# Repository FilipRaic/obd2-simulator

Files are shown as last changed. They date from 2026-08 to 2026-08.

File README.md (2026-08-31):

# OBD-II Simulator

Open-source OBD-II simulator board that answers a diagnostic tool over CAN
exactly as a vehicle ECU does. The repository has three parts:

- the **protocol core** (`include/`, `src/`, `tests/`) - portable,
  host-testable protocol and simulation layers with no external
  dependencies, described below,
- the **firmware** (`firmware/`) - PlatformIO project for the device
  itself (FreeRTOS tasks, MCP2515 SPI driver, TFT_eSPI user interface,
  16 MB SPI NOR flash storage with USB-C MSC / USB-A stick transfer), which
  compiles the core unchanged and plugs into it through the small set of
  `extern` platform hooks listed below. See `firmware/README.md`,
- the **board** (`hardware/`) - the KiCad project, gerbers, bill of
  materials and the scripts that generate the board, at revision **v0.7**
  (130 x 115 mm, two-layer FR4, ESP32-S3-WROOM-1). See `hardware/README.md`.

Block diagram of the OBD-II simulator, five functional blocks

The simulator answers a diagnostic tool over CAN and, like a real vehicle, powers
it from pin 16 of the J1962 connector. The protocol core described below is what
runs inside the "Microcontroller" block, and everything around it is documented
in [`hardware/README.md`](hardware/README.md), which walks through the same
schematics one design decision at a time.

Everything in the repository is in English. The project also keeps a set of
Croatian working documents, which live outside it.

The **v0.7 board has been fabricated and assembled** in one unit. A commercial
ELM327 adapter connects to it, reads all 21 parameters and the fault codes, and
draws its own 12 V from pin 16 while doing so.

## The website

The project has a landing page at **<https://filipraic.github.io/obd2-simulator/>**,
which is the short version of everything below: what the device does, what it is
built from and where to get the files. Two things on it are worth opening even if
the page itself is skipped, because neither can be shown in a README:

| Page | What it is |
|---|---|
| [The user interface demo](https://filipraic.github.io/obd2-simulator/UI-demo/) | the screens `firmware/src/ui/screens/` draws on the display, redrawn in a browser and walked with the same encoder and joystick controls the device has, so the interface can be tried before anything is built |
| [The interactive board view](https://filipraic.github.io/obd2-simulator/OBD2-board-v0.7/) | the v0.7 board drawn in the browser, with the tracks, the ground pour, the vias, the pads and the components as five layers that switch on and off, and a tooltip on every part. Generated from `obd2-simulator.kicad_pcb` by `hardware/kicad/scripts/generate_pcb_html.py` |

## Where to read what

The wiki is written for someone using or rebuilding the device. The files in
this repository are the record of how it was built and why. The wiki is in
English, which is the language of the project. A Croatian translation of the
same pages exists but is not published yet, and if it goes up it will take an
`-HR` suffix, leaving the page names below unchanged.

| Question | Wiki page | In this repository |
|---|---|---|
| What is this and what can it do | [Home](../../wiki/Home) | this file |
| How do I build one | [Building the device](../../wiki/Building-the-device) | [`hardware/README.md`](hardware/README.md), and [`hardware/gerber/README.md`](hardware/gerber/README.md) before ordering |
| How do I compile and flash it | [Firmware](../../wiki/Firmware) | [`firmware/README.md`](firmware/README.md), and [`firmware/tools/README.md`](firmware/tools/README.md) when the ordinary upload path is unavailable |
| How do I drive it | [Usage](../../wiki/Usage) | [`scenarios/README.md`](scenarios/README.md) for the JSON format |
| How do I contribute | [Contributing](../../wiki/Contributing) | the conventions below |
| How is the board generated | - | [`hardware/kicad/scripts/README.md`](hardware/kicad/scripts/README.md) |

Two internal documents govern changes to this project, and neither is published
here: `docs/MAPA-POVEZANIH-DATOTEKA.md` is an "if you change X, check Y" table,
because the same fact is written down in up to six places, and
`docs/combined/DNEVNIK-IZMJENA.md` is the chronological record of every decision.
Both are in Croatian and are working notes rather than product documentation, so
`docs/` is deliberately left out of the repository.

## Modules

| File | Purpose |
|---|---|
| `include/obd2_pids.h` | Mode/PID constants per SAE J1979 / ISO 15031-5 |
| `include/sensor_table.h` | 21 simulated parameters with ranges and noise |
| `src/pid_encoder.cpp` | Value → raw bytes codec + supported-PID bitmasks |
| `include/dtc_bank.h` | DTC bank (pending/confirmed, MIL, freeze frame) |
| `src/iso_tp.cpp` | ISO 15765-2 transmit path (SF, FF/FC/CF) |
| `src/can_handler.cpp` | Request dispatcher, modes 0x01-0x09 |
| `src/simulator_core.cpp` | Simulation profiles (Manual / Idle / Drive) |
| `tests/test_simulator.cpp` | Host-side unit tests |

Implemented services: 0x01 (current data, 21 PIDs), 0x02 (freeze frame),
0x03/0x07 (stored/pending DTCs), 0x04 (clear DTCs), 0x09 (VIN).
Unsupported services receive the negative response `7F <mode> 11`.
Requests are accepted on 0x7DF (functional) and 0x7E0 (physical), while
responses are sent on 0x7E8. Frames are padded to 8 bytes with 0x55
per ISO 15765-4.

## Platform hooks (implement on target, stubbed in tests)

```cpp
uint32_t millis();                                // ms since boot
void     can_send_frame(const CanFrame& frame);   // MCP2515 transmit
bool     iso_tp_wait_flow_control(FlowControl&);  // wait for FC frame
void     iso_tp_delay_us(uint32_t us);            // STmin pacing
```

## Building and running the tests

```sh
cmake -B build
cmake --build build
ctest --test-dir build --output-on-failure
```

The same tests also run through PlatformIO (`pio test -e native` inside
`firmware/`). Firmware build: `pio run -e custom-board` (the dedicated
ESP32-S3 board, also used on the breadboard adapter during development).

## Regenerating the board

The board is generated rather than drawn: there is no `.kicad_sch`, and the
`.kicad_pcb` is an output. Two entry points, and picking the wrong one costs
work:

```powershell
# a part, a net or the placement changed - rebuilds and re-routes from nothing
powershell -ExecutionPolicy Bypass -File hardware\kicad\scripts\route_board.ps1

# the board file is already right, only the derived files are stale
powershell -ExecutionPolicy Bypass -File hardware\kicad\scripts\regen_outputs.ps1
```

`route_board.ps1` ends by recomputing all 103 reference designator positions and
so **discards the hand-tuned silkscreen**. If no copper moved, run only
`regen_outputs.ps1`. Every step of the chain, what it writes and where, is in
[`hardware/kicad/scripts/README.md`](hardware/kicad/scripts/README.md).

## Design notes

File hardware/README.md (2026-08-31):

# OBD-II simulator board, revision v0.7

The final hardware of the project: a dedicated two-layer board **130 x 115 mm**
with an ESP32-S3-WROOM-1 module, the CAN chain MCP2515 -> SN65HVD230 ->
PESD1CAN -> J1962F, and power over USB-C Power Delivery.

Block diagram of the OBD-II simulator, five functional blocks

The five blocks in that diagram are the ones the rest of this document keeps
naming: **power** (USB-C PD to 12 V and 3,3 V), the **CAN and OBD interface**
(MCP2515 to SN65HVD230 to the J1962F socket), the **microcontroller**, **memory
and USB**, and the **user interface**. The dashed arrow is the diagnostic tool,
which the simulator both answers and powers, over pin 16 of the connector.

Every figure in this file is drawn by `kicad/scripts/generate_figures.py`. It
draws them **by hand rather than deriving them from the board**, so a figure does
not follow a board change on its own, and after a change to the schematic it has
to be redrawn there. The full set is listed in [Figures](#figures) below.

The board **has been fabricated and assembled** in one unit, and the core of the
device was verified on it with a commercial ELM327 adapter. Numbers about the
board itself are still measured from the project file
`kicad/obd2-simulator.kicad_pcb` or taken from tool output, never copied from an
earlier version of this text.

Wiki page for anyone building one: **Building the device**, on the repository
wiki. It has the bill of materials, the pinout and the first-power-up procedure. This
file is the design record behind those instructions, decision by decision.

**How the board is generated is a subject of its own**, and it has its own index
in [`kicad/scripts/README.md`](kicad/scripts/README.md): which of the two entry
points to run, what each step of the routing chain is for and which derived file
lands where.

## Board state (measured with the tools)

| Item | State |
|---|---|
| Outline | 130 x 115 mm, two-layer FR4 1,6 mm, 4 x M3 in the corners (spacing 120,00 x 105,00 mm) |
| Footprints | **107** (95 parts to solder + 8 test points + 4 mounting holes), of which **16 SMD** |
| Nets | **64 named**, ground included |
| Routing | **892 segments** (639 top layer, 253 bottom), **73 vias** (72 x 0,60 / 0,30 mm and one x 0,80 / 0,40 mm on V5_STICK), fully routed |
| DRC | **0 errors, 0 warnings, 0 unconnected** (`kicad-cli pcb drc --severity-all`) |
| Mask | black, silkscreen white, ENIG finish |
| Components | all on the top side, the bottom is copper, mask and legend only |

A note on that DRC: it is clean **partly because some rules are switched off**.
The project has `min_silk_clearance = 0` and
`solder_mask_to_copper_clearance = 0`, and `missing_courtyard` is set to
"ignore". The claim "0 warnings" therefore does not by itself mean the silkscreen
has been checked.

**Checked separately on 10.08.2026.** by running DRC over a copy of the project
with those rules restored (`min_silk_clearance` 0,15 mm,
`solder_mask_to_copper_clearance` 0,05 mm, hole spacing 0,50 mm). Outcome:

| Finding | Count | Verdict |
|---|---|---|
| Silkscreen over a pad | **0** | clean, the earlier suspicion is settled |
| Mask bridge between nets | **0** | the openings do not merge, but the bridges are 0,150 mm, see below |
| Silkscreen clipped by the board edge | 2 | J4, 0,140 mm, cosmetic |
| Hole spacing under 0,50 mm | 21 | see `gerber/README.md`, the geometry of connector J1 |
| Footprint type does not match its pads | 1 | U1, an attribute of a custom footprint, no effect on fabrication |

## Contents of this directory

| Contents | What it is |
|---|---|
| `kicad/obd2-simulator.kicad_pcb` | The KiCad board project: footprints, netlist, placement, routing, ground pour, keepout around the antenna |
| `kicad/scripts/` | the scripts that generate the board (KiCad Python API + Freerouting), together with `PRE-FABRICATION-CHECKLIST.md` |
| `kicad/scripts/docx/` | `.docx` tooling that needs no Word: `md2docx.py` builds the technical documentation from Markdown, the rest edit text, tables and the table of contents. Moved here 15.08.2026., has its own `README.md` |
| `kicad/footprints/obd2.pretty/` | custom footprints: CH224K, SEP-A-OBD-D2, SKRHABE010, RK12L12C0A0G |
| `kicad/3dmodels/` | custom VRML models for the render, generated by `scripts/gen_3dmodels.py` |
| `kicad/render-top.png`, `render-bottom.png` | 3D renders of both sides, **embedded in this README**, so a stale render is visible on GitHub |
| `gerber/` | Gerber layers, Excellon drill, gbrjob and the package for the fabricator |
| `schema1.svg` - `schema4.svg`, `blok.svg`, `canchain.svg` | schematics and the block diagram, in English, generated by `scripts/generate_figures.py`. **Not used in the written documentation**, see the note below the table |
| `kicad/scripts/fig/` | every figure the generator draws. The six above are copied up into this directory, and three more are used from here: `zones.svg` (functional zone layout), `nets.svg` (all net groups with their routing rule) and `ip2368.svg` (the external circuit of the CH224K, the file name is that of the part the design started with) |
| `bom/bom-pcb.csv` | parts list with suppliers, order codes and prices |
| `bom/bom-pcb.md` | quantities, values, tolerances and packages, with soldering notes |

The 1:1 print document (`pcb-ispis-1-1-v07.docx`) and the figure generator of
the written documentation (`alati/figgen/`) are **not in this repository**. They
exist only for that document and live beside it. Every other script of
the project, including the ones that write into that directory, has lived here
in `kicad/scripts/` since 15.08.2026.

The **dimensioned drawing** (`tehnicki-crtez-pcb-v07.svg` and `.png`) has lived
there too, in `Slike za rad/crtezi-ploce/`, since 15.08.2026., and
`regen_outputs.ps1` writes it straight into that directory. The English
schematics stay here, because this repository is in English.

The Croatian set of nine figures that used to be generated alongside them **is no
longer produced, and the files that were there have been deleted**. Comparing the
MD5 sums of every image in the written documentation showed nothing uses them, so
`--lang hr` was dropped from `regen_outputs.ps1`. The flag itself still works, if
a Croatian schematic is ever needed:

```powershell
& "$env:LOCALAPPDATA\Programs\KiCad\10.0\bin\python.exe" `
    kicad\scripts\generate_figures.py --lang hr
```

> ⚠️ **The schematics in this directory are not the ones in the written
> documentation.** That document embeds a **different** set of figures, from its
> own generator (`alati/figgen/`). The file names are the same
> (`schema1` to `schema4`, `blok`, `canchain`, `nets`, `zones`), but they are
> different drawings from a different generator. Verified on 15.08.2026. by
> comparing MD5 sums: every PNG from `figgen/out/` is embedded verbatim in that
> `.docx`, and from the board only the render `kicad/render-top.png` and the
> dimensioned drawing `tehnicki-crtez-pcb-v07.png`.
>
> The practical consequence: **changing a schematic here changes nothing in that
> document.** If a figure is needed there too, `figgen` is what gets edited. There
> is no longer a third group of identically named files, because the Croatian
> schematics in `crtezi-ploce/` were deleted on 15.08.2026.

## Figures

Nine drawings, and each one answers a different question. They are used
throughout this document where they explain a decision, and this is the index:

| Figure | Answers |
|---|---|
| [`blok.svg`](blok.svg) | What the device consists of and what talks to what. Start here |
| [`schema1.svg`](schema1.svg) | How 12 V and 3,3 V are made, and where the tool power on pin 16 comes from |
| [`schema2.svg`](schema2.svg) | The CAN interface end to end, MCP2515 to SN65HVD230 to termination to ESD to J1962F |
| [`schema3.svg`](schema3.svg) | The ESP32-S3 module, external flash U7 and the USB subsystem, with the SPI series termination and the test points |
| [`schema4.svg`](schema4.svg) | The user interface: display, encoder, the 5-way switch and the three buttons, with the filters |
| [`canchain.svg`](canchain.svg) | Only the CAN chain, in the order it is actually routed, with the measured distances |
| [`kicad/scripts/fig/zones.svg`](kicad/scripts/fig/zones.svg) | Which functional group sits where on the 130 x 115 mm outline |
| [`kicad/scripts/fig/nets.svg`](kicad/scripts/fig/nets.svg) | Every net group, its ESP32-S3 pins and the rule its routing had to obey |
| [`kicad/scripts/fig/ip2368.svg`](kicad/scripts/fig/ip2368.svg) | The external circuit of the CH224K PD sink, that is how one resistor picks the voltage |

To read the board itself rather than the intent, the two renders below show
what was actually built. They come out of `regen_outputs.ps1`, straight from
`obd2-simulator.kicad_pcb` with the board stackup colours, so they are the
board and not a drawing of it.

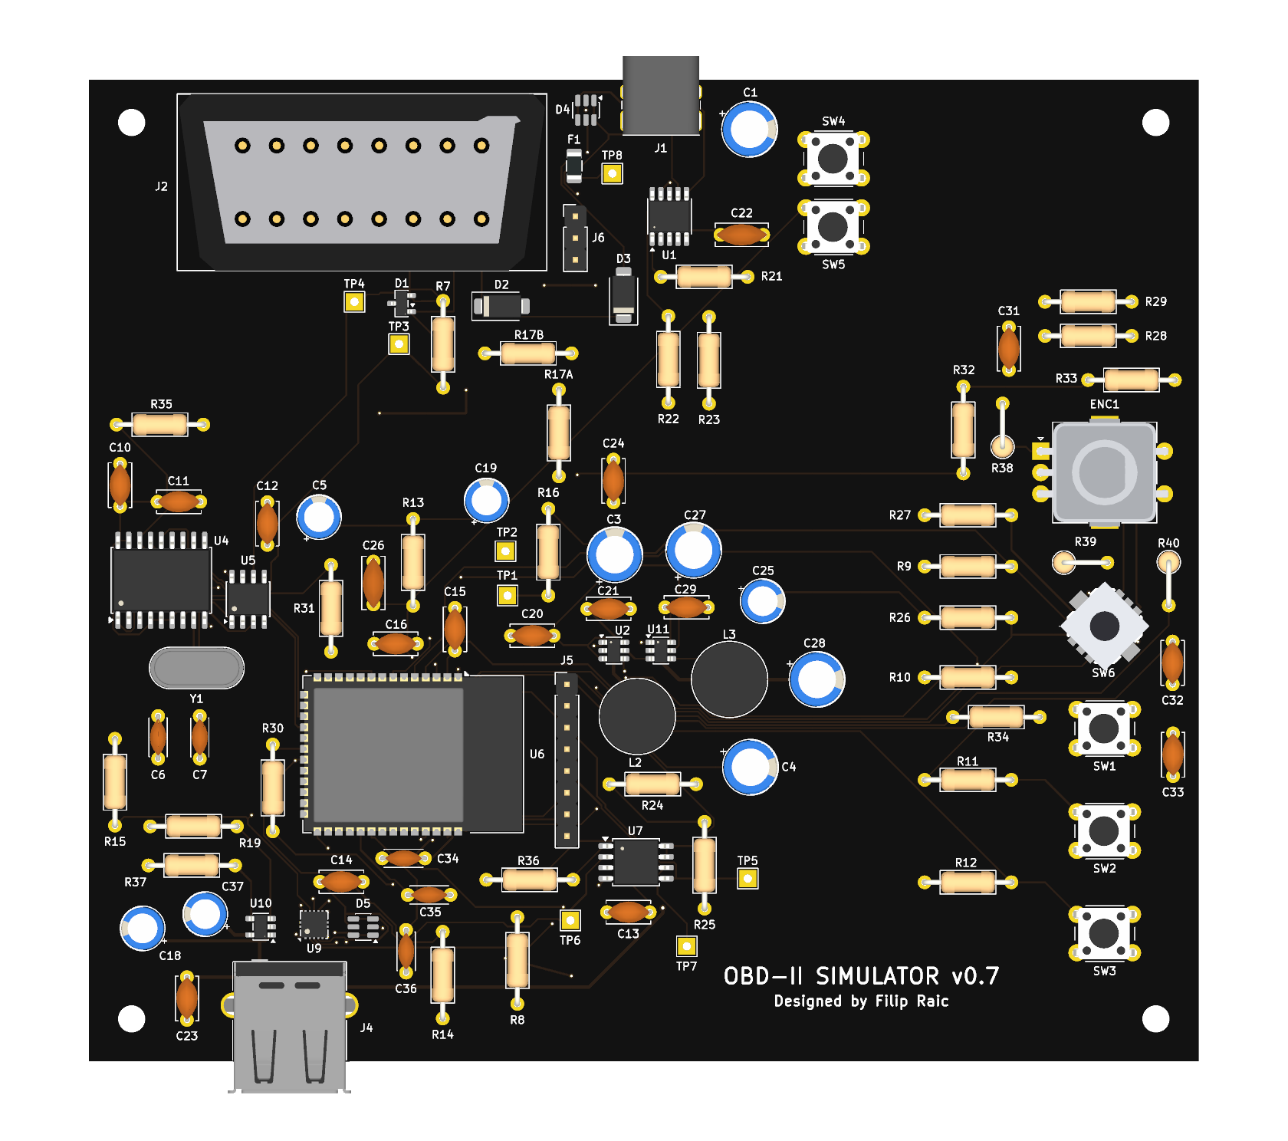
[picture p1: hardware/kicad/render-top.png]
Top side of the assembled board: the ESP32-S3 module, the display, the encoder and the CAN chain


The top side carries every component and the whole silkscreen, so this is the
view to compare a placement change against.

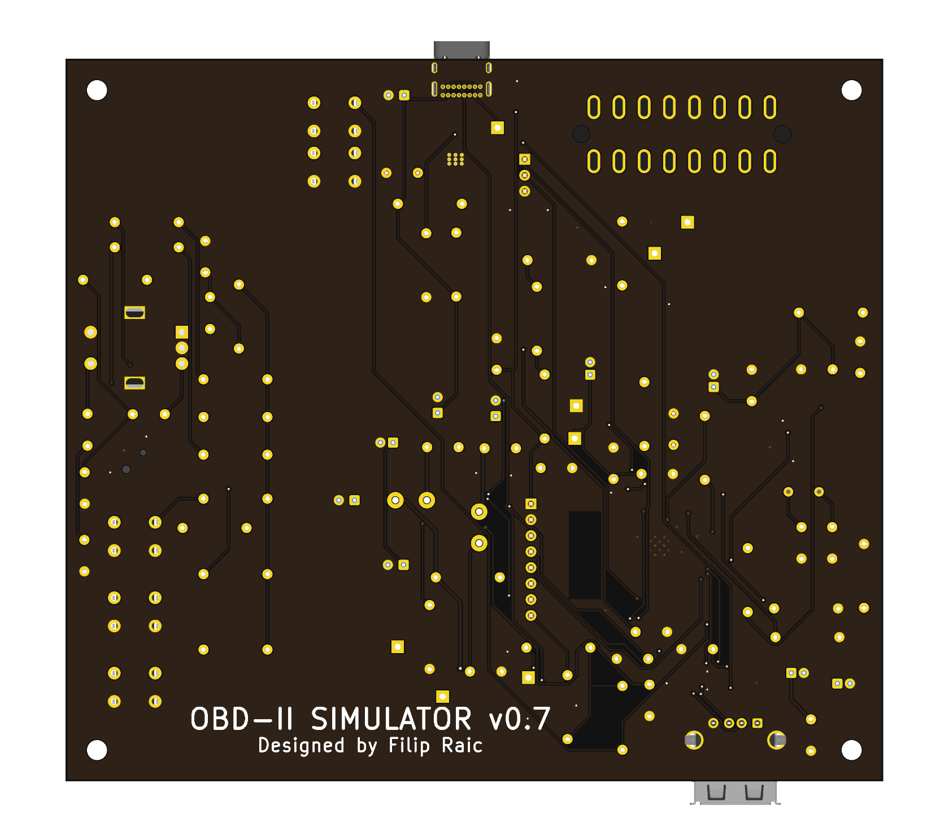
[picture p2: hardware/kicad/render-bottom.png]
Bottom side of the board, copper and the through-hole pads


The bottom side is copper and pads only, which is why a silkscreen edit leaves
it byte for byte identical while a re-route changes it.

---

# Why the board is the way it is

## Size: 130 x 115 mm

With all-through-hole passives every pad blocks **both** layers, so a two-layer
autorouter quickly runs out of corridors. Tried and documented:

| Size | Resistors | Result |
|---|---|---|
| 100 x 80 | vertical | at least one net always fails (CC2, then BTN_CLEAR, then JOY_SW) |
| 100 x 90 | vertical | JOY_SW and CS_FLASH fail |
| 105 x 100 | vertical | everything routes |
| 115 x 100 | horizontal | everything routes, but with no room for the 17 extra footprints the review asks for |
| **130 x 115** | **horizontal** | **107 footprints, every net routed, DRC clean** |

The space was added by moving the groups **tied to an edge** out to the new edge
and leaving the rest where it was. That opened two free bands into which the
packer drops the new parts: a vertical one at x = 96..111 and a horizontal one at
y = 84..99.

Functional zone layout on the printed circuit board

The zone map shows what "the groups tied to an edge" means. The OBD connector J2
and USB-C J1 share the top edge, USB-A J4 sits on the bottom one, and the whole
user interface stands on a single vertical axis along the right edge, so the
parts that must reach a connector never have to cross the board. What is left in
the middle is the routing space the numbers above are about.

Signal tracks were narrowed from 0,25 to **0,20 mm**. The gap between two THT
pads on a 2,54 mm grid is about 0,94 mm, so those 0,05 mm decide whether a net
gets through. The documentation allows 0,15 mm, currents are below 0,5 A per
branch, and ground is a pour.

Four short supply nets (SW_3V3, SW_5V, V5_STICK, VBUS_STICK) have their own
**Power class with a 0,40 mm width**. This is not a repeat of the abandoned
attempt with net OBD_12V: there, 0,50 mm went to a long track crossing the whole
board and closed the corridor used by CS_FLASH and BTN_RETURN, so the board
failed DRC. These four are short and local, right at the converters and at the
USB-A socket, and cross no corridor.

## The power section respects the TPS562201 datasheet

Schematic 1: power section

The schematic is the map for the table below: USB-C into the CH224K, 12 V out of
it to pin 16 of the OBD connector through F1, D3 and D2, and the same 12 V into
the two TPS562201 converters that make 3,3 V and 5 V.

This is the only review finding that changed function rather than tidiness.

| | before | now | Datasheet (SLVSD91D) |
|---|---|---|---|
| L2, L3 | 10 µH | **4,7 µH** | table 7-2: 3,3 µH typ. and 4,7 µH **max** for 3,3 V, 4,7 µH typ. and max for 5 V |
| C3, C4, C27, C28 | plain electrolytic, ESR ~1 Ω | **low ESR, ESR ≤ 0,15 Ω** | 7.2.2.3: "ceramic or other low-ESR capacitors, 20 to 68 µF" |
| Ripple on 3,3 V | about 0,9 V | **about 30 mV** | |
| C at the input of U10 | only 100 nF (nearest electrolytic 73 mm away) | **C37, 10 µF right at the pin** | |

Those two items were linked. The inductor had once been raised from 2,2 to 10 µH
to cut the ripple current through the electrolytic, which treated the symptom.
The cause was the choice of capacitor. Now that they are low ESR, the inductor
can go back into the range the manufacturer specifies.

**The criterion is impedance, not chemistry** *(rewritten 10.08.2026.)*. It used
to demand a polymer part explicitly, even though the datasheet says "ceramic
**or other low-ESR**". The measurable form is **ESR at 100 kHz ≤ 0,15 Ω** with a
**rated ripple current ≥ 0,35 A rms**. Those capacitors carry 0,88 A peak to peak
on the 3,3 V rail and 1,07 A on the 5 V rail:

| Capacitor | ESR | Ripple on 3,3 V | Ripple on 5 V | Verdict |
|---|---|---|---|---|
| Polymer | 20 to 50 mΩ | 26 mV | 32 mV | ideal |
| Electrolytic marked "low ESR" | up to 150 mΩ | 132 mV | 161 mV | **usable, this is what is fitted** |
| Plain electrolytic | about 1 Ω | 878 mV | 1070 mV | unusable |

The ESP32-S3 wants 3,0 to 3,6 V and the flash 2,7 to 3,6 V. At 132 mV the rail
moves between 3,234 and 3,366 V, with margin. With a plain electrolytic it moves
between 2,86 and 3,74 V, outside the specification of both chips, and the ripple
current of 0,25 to 0,31 A is above what a part of that size can take anyway.

If the measured ESR turns out worse than 0,15 Ω, the answer is not a different
electrolytic but a **ceramic 4,7 to 10 µF across the same pads**: at 580 kHz its
impedance is some tens of mΩ and it takes over the ripple current.

The lower member of the 3,3 V feedback divider is not a single 15,4 kΩ resistor
but **two in series, R17A = 15 kΩ and R17B = 470 Ω**, joined by net `FB_MID`. The
reason is availability: 15,4 kΩ exists only in the E96 series and could not be
bought in a through-hole part.

| Lower member | Output |
|---|---|
| 15 kΩ + 470 Ω = 15,47 kΩ (as built) | **3,300 V** |
| 15,4 kΩ (originally) | 3,311 V |
| 15 kΩ alone | 3,379 V, **unusable** |

With the feedback tolerance, 15 kΩ on its own heads towards 3,45 V, and the NOR
flash U7 has an absolute maximum of 3,6 V, so no margin would be left. The series
pair does not worsen the tolerance (±150 Ω plus ±4,7 Ω on 15,47 kΩ is still
±1 %), and dissipation is irrelevant, 49,6 µA flows through the divider.

## The CH224K does not sit on the data pair

External circuit of the CH224K USB-C PD sink controller

The whole PD side of the board is that one figure: the CC lines to the
controller, a single resistor to pick the voltage, and the charger puts it on
VBUS. Note that DP and DM leave the controller unconnected, and this is why.

The DP and DM pins of the controller used to be connected to USBC_DP and
USBC_DM, that is to the same pair the ESP32 uses to talk to a PC, which is also
the primary programming path (USB-Serial-JTAG) and the MSC mode. Section 5.5 of
the CH224 datasheet says, verbatim: *"If you want to shield these protocols on
CH224K/CH224D, you need to disconnect the DP/DM pin of CH224K/CH224D from the
Type-C interface."* The PD contract is negotiated purely over the CC lines, so
those two pins are left unconnected.

## The CAN pair is a chain, not a tree

CAN chain: MCP2515 to SN65HVD230 to termination to ESD protection to J1962F

Schematic 2: CAN interface

The first figure is the prescribed order together with the distances actually
achieved, the second is the same chain with the parts around it: the 8 MHz
crystal Y1 on the MCP2515, the SPI lines back to the module, and the 12 V that
leaves for pin 16 of the connector. The order is the point: the 120 Ω
termination R7 comes before the ESD diode D1, and D1 sits as close to the
connector as the 43,3 x 20,7 mm connector body allows, 9,0 mm from pin 14.

The checklist asks for `SN65HVD230 -> R7 -> D1 -> J1962F` without branches,
without vias and with roughly equal lengths. Machine-routed, the pair was none of
that:

| | machine-routed | now |
|---|---|---|
| Topology | R7 is a node with **three branches**, D1 hangs off a 13,0 mm stub (CANH) and a 4,3 mm one (CANL) | a chain, no branching |
| Vias | 1 on CANL, 0 on CANH | **0 on both** |
| Layers | both pairs across F.Cu and B.Cu | both on **F.Cu only** |
| Lengths | 73,7 and 56,9 mm, difference 16,8 mm | 83,9 and 62,2 mm, difference 21,7 mm |

The cause was not the placement but the fact that Freerouting routes a minimal
tree and knows nothing about a prescribed order. The placement was improved (D1
anchors to the connector, R7 to D1, the test points to D1), but placement alone
cannot force a topology on the router. The pair is therefore routed by its own
script, `kicad/scripts/route_can_chain.py`, and it runs **before** Freerouting,
while the top layer is still empty. `dsn_export.py` hands those tracks over as
immovable (`(type protect)` instead of `(type route)`), so the router routes
around them.

The length difference stayed at about 20 mm and cannot get smaller without moving
parts: it comes from the leads of termination R7 being 10,16 mm apart and the two
pin rows of connector J1962F being 8,6 mm apart, 18,8 mm together. At 500 kbit/s
that is 0,13 ns on a bit of 2000 ns.

## Smaller, but real findings

| Finding | Fix |
|---|---|
| On 09.08. D3 was switched to a Schottky SS34 on the claim that a TVS has no rating for continuous forward current | **withdrawn 10.08.2026., D3 is an SMAJ16A again.** The datasheet gives `PD` = 3,3 W and `RθJA` = 120 °C/W, and the worst case is 0,45 W. See the section below |
| Both USB connectors without any ESD protection, while the CAN pair has D1 | **D4, D5** (USBLC6-2SC6). Pin 5 to +3,3 V, not to VBUS, because its standoff is 5,25 V |
| CS_CAN and CS_FLASH float until the firmware takes the pin over | **R35, R36** (10 kΩ pull-up) |
| USB_HOST_EN floats, and the EN of the switch is active high | **R37** (10 kΩ pull-down) |
| A 10 nF encoder filter gives 100 µs, while contact bounce lasts on the order of ms | **47 nF** (470 µs) |
| The filter capacitor discharges straight through the encoder contact, a spike of several amperes through a contact rated for 10 mA | **R38-R40**, 100 Ω in series right at the contact, mounted vertically |
| V5_STICK 100 mm at 0,20 mm, about 0,25 Ω, a quarter of a volt dropped at 1 A | net class **Power, 0,40 mm** on V5_STICK, VBUS_STICK, SW_3V3, SW_5V |
| The inductor footprint drew a Ø5 mm body while the BOM asked for "up to Ø9 mm", so the courtyard was smaller than the part and DRC would not report a collision | footprint at **Ø7,5 mm**, BOM at "up to Ø7,5 mm" |
| The inductor footprint was axial and mounted vertically, so it drew the body over one hole, while the radial part that was bought sits centred between two | **`L_Radial_D8.7mm_P5.00mm_Fastron_07HCP`**, 5,00 mm pitch, BOM at "up to Ø8,5 mm" |
| The board legend was a wish only, the packer knew nothing about it | the space is reserved **before** packing |
| An SPI bus 88 to 126 mm long with three loads and no termination | **R30, R31**, 33 Ω in series right at the module pin, with the new nets SCK_MCU and MOSI_MCU |
| The checklist asks for eight test points and the board had none | **TP1 - TP8**, each beside the pad of its own net, that is in line rather than on a stub |
| The shield of USB-A socket J4 was on no net at all: the script assigned ground to pads "5" and "6" while the footprint calls them `SH` | both tabs on **ground**, joined by the pour flooding on the bottom layer. Found 10.08.2026. by comparing the netlist from the script with the netlist of the finished board |

## ENC1: an incremental encoder instead of a potentiometer

Schematic 4: user interface section

Everything the user touches is in this one figure: the ILI9341 display, encoder
ENC1 with its filter at both ends, the 5-way switch SW6 on the resistor ladder,
and the three CONFIRM / CLEAR / RETURN buttons.

The rotary potentiometer was replaced by an **incremental encoder with a
button**, a BI Technologies EN11-HSB1AQ20, 20 pulses and 20 detents per
revolution.

| | potentiometer | encoder |
|---|---|---|
| Kind of signal | analogue, absolute position | digital, relative steps |
| Pins | GPIO1 (ADC1_CH0) | GPIO1 (A), GPIO38 (B), GPIO39 (button) |
| Nets | POT | ENC_A, ENC_B, ENC_SW |
| Firmware | ADC read, filter, hysteresis, correction of the logarithmic law | quadrature decoder in an interrupt handler, step size depending on turn speed |

That removed the function `pot_linearize()` from the firmware, which existed only
because the potentiometer that had been bought had a logarithmic (audio) 15A law.

**The footprint is the stock KiCad
`RotaryEncoder_Alps_EC11E-Switch_Vertical_H20mm`**, not a custom one. The EN11
belongs to the same family of 11 mm encoders and has the same lead arrangement:
A, C and B on a 2,5 mm pitch on one side, two button contacts on the other and
two mounting tabs. Using a ready-made, proven footprint is considerably safer
than drawing a new one, but **it is also the one item that must be measured
before the board is ordered**.

Resolution is handled by acceleration: the step is 1/256 of the range on a slow
turn, 1/64 on a medium one and 1/16 on a fast one, so the full range is crossed
in roughly one quick turn.

The shaft falls on the interface axis x = 104 at height y = 69, exactly where the
potentiometer shaft used to be. Joystick SW6 and the CONFIRM, CLEAR and RETURN
buttons share that vertical axis.

## D3 is an SMAJ16A, not a Schottky

The blocking diode on the branch towards pin 16 exists because F1 is a PTC fuse
and conducts both ways, so external 12 V from a vehicle or from a tool that
powers the line itself would flow back into `VBUS`, into the inputs of both
converters and onto the USB-C connector.

Between 09.08. and 10.08.2026. an **SS34** stood there, on the grounds that a TVS
diode has no rating in its datasheet for continuous forward current, only `IFSM`
for an 8,3 ms pulse. **That reasoning was too strict and has been withdrawn.**

The SMAJ series datasheet (Littelfuse, rev. 10/2020) gives exactly what is needed
to bound continuous forward operation: `PD` = **3,3 W** and `RθJA` =
**120 °C/W**. Only the `IF(AV)` figure is missing, not the thermal data. F1 limits
the branch to 500 mA, and a scan tool draws 25 to 50 mA:

| | 50 mA (ELM327) | 500 mA (F1 limit) |
|---|---|---|
| Power in the diode | 35 mW | **0,45 W** out of 3,3 W |
| Junction temperature rise | 4 °C | **54 °C**, junction at about 79 °C out of 150 °C |
| Voltage at pin 16 | about 11,3 V | about 11,1 V |
| The same with an SS34 | 11,7 V | 11,6 V |

So there never was a thermal problem, and the voltage difference is about 0,4 V,
while tools per J1979 work from roughly 9 V upwards.

| | SS34 | SMAJ16A |
|---|---|---|
| Reverse voltage | 40 V | **16 V**, breakdown 17,8 to 19,7 V |
| Reverse leakage | hundreds of µA, milliamperes at 100 °C | **< 1 µA** |
| Forward drop at 50 mA | about 0,45 V | about 0,7 V |
| Sourcing | a new type | **already ordered, a second piece alongside D2** |

The concession is reverse margin above 18 V, and that only matters if the
simulator is ever plugged into a real vehicle. This board is the source of those
12 V, not a consumer. In exchange the leakage is a thousand times lower, and
blocking is the only purpose of that diode.

The swap does not touch the board: the same SMA package (DO-214AC), the same
`D_SMA` footprint, and **pad 1 is the cathode on both**, so the same orientation
and the same silkscreen. D2 and D3 thereby become the same part and cannot be
mixed up when soldering.

## Corrected polarity of TVS diode D2

In the first prototype D2 was connected with its **cathode to ground and its
anode to +12 V** (pad 1 = GND, pad 2 = OBD_12V). Pad 1 is the cathode by KiCad
convention, and the SMAJ16A is a unidirectional TVS (a bidirectional one would be
an SMAJ16**CA**). Connected that way the TVS conducts forward at about 0,8 V and
effectively shorts the 12 V branch towards pin 16 of the connector, tripping the
PTC fuse continuously. Now **pad 1 (cathode) is on OBD_12V and pad 2 (anode) on
ground**.

## Every passive is through-hole

Resistors, capacitors and inductors are through-hole parts. What stays SMD is the
**integrated circuits, the module, the diodes, the fuse and the joystick**, 16
footprints in total: U1 CH224K, U2 and U11 TPS562201, U4 MCP2515,
U5 SN65HVD230, U6 module, U7 flash, U9 TS3USB221, U10 SY6280, D1 PESD1CAN, D2 and
D3 SMAJ16A, D4 and D5 USBLC6-2SC6, F1 1206L050 and SW6 SKRHABE010.

D4 and D5 carry the DNP flag, so a board assembled without them has 14 SMD parts.
The figure comes from counting footprints with `(attr smd)` in the `.kicad_pcb`,
and that is how it should be checked, because a list written out by hand is
easily left short.

The fuse and the TVS deliberately stayed SMD: they are neither resistor, nor
capacitor, nor inductor, and those packages solder easily with a hand iron, so
there is no reason to spend space on through-hole substitutes. Joystick SW6 has
no through-hole version.

The resistors **lie flat**, on a **10,16 mm** pitch with a DIN0207 body
(6,3 x 2,5 mm), that is a standard 1/4 W resistor. That pitch also takes smaller
bodies, since leads can always be spread wider. Vertical mounting (2,54 mm pitch)
would save about 590 mm² across 21 resistors, but is harder to hand-solder.

**The only exception is R38-R40**, the series resistors in the encoder filter,
which stand vertically on a 5,08 mm pitch. That is out of necessity rather than
thrift: they have to sit right at the encoder contact, and the column along the
right-hand edge already carries the encoder, the joystick, three buttons and nine
pull-ups.

The ceramic capacitors are on a **5 mm** pitch, because that is how they are
sold. Without it the part that was bought could not be pushed into the board.

## Placement: the order is electrical, not tabular

Parts that must sit next to a particular pad are placed by **priority**, not in
the order of the component table. The rule: the faster the loop, the earlier it
goes. Nine parts compete around a single SOT-23 converter, and a ring of 12 mm
radius has about 490 mm², just enough for all of them, but only if the most
important ones choose first. In table order the first to choose was C1, a 100 µF
bulk capacitor to which proximity means nothing, while bootstrap C21 ended up at
12,5 mm.

On top of that **all four rotations** are tried and the distance is measured **to
the pad on the same net**, not to the footprint origin. A horizontal resistor is
10,16 mm long between its holes, so by the old measurement R16 was "11,5 mm from
the FB pin" while it really was 21,1 mm, because it faced the wrong way.

### Measured distances to supply and sensitive pins

| Connection | before | now |
|---|---|---|
| C21 bootstrap to the BST pin of U2 | 14,0 mm | **5,8 mm** |
| C29 bootstrap to the BST pin of U11 | 15,5 mm | **4,2 mm** |
| L2 to the SW pin of U2 | 9,2 mm | **6,5 mm** |
| L3 to the SW pin of U11 | 20,9 mm | **7,5 mm** |
| C15 to pin 2 of the module | 14,0 mm | **3,5 mm** |
| C16 to pin 2 of the module | 18,5 mm | **5,5 mm** |
| Y1 to OSC1 | 7,3 mm | **6,0 mm** |
| R7 termination to J2.14 | 18,5 mm (to pin 6) | **9,5 mm** |
| D1 ESD to J2.14 | 18,6 mm (to pin 6) | **9,4 mm** |
| R30 to pin 20 of the module | - | 4,0 mm |
| D3 to F1 | - | 4,6 mm |

| Net | before | now |
|---|---|---|
| FB_3V3 | 39,4 mm | **24,6 mm** |
| FB_5V | 57,9 mm | **32,1 mm** |
| SW_3V3 | 30,1 mm | **25,0 mm** |
| SW_5V | 42,3 mm | **20,4 mm** |
| MOSI | 100,3 mm | 91,6 mm |
| MISO | 91,6 mm | 87,7 mm |
| SCK | 105,3 mm | 125,9 mm |
| CANH / CANL | 61,9 / 60,9 mm | 73,8 / 57,9 mm |
| VBUS | 114,6 mm | 201,2 mm |

Several nets are longer than before. The board is 15 mm wider and 15 mm taller,
so anything crossing it grows by about 15 %. VBUS is longer because bulk
capacitor C1 moved from the converter input to the VBUS pin of the USB-C
connector, where it belongs, giving the net one more long arm.

Summary of every net on the device

The net overview is what a change gets checked against before it touches the
board: which ESP32-S3 pin carries which signal, and what rule that group is
routed under. The rules easiest to break by accident are the 33 Ω series
resistors at the source of the SPI bus, the CAN pair with no stubs and no vias
entirely on the top layer, and the 0,40 mm Power class on the four short supply
nets.

## Silkscreen

Reference designators (R1, C3, U6 …) are on the top silkscreen, **all horizontal,
all 0,9 mm high and all beside their part**. Silkscreen over a track is
**allowed**: it is printed over the solder mask, that is after the copper, so an
overlap with a track has no consequence. What is not conceded is a designator
over a pad, over another designator, or outside the board outline.

**The final designator placement was hand-tuned in KiCad** and is authoritative
as it stands in the `.kicad_pcb`. The script
`kicad/scripts/place_silk_after_route.py` only provides a starting placement, and
**running it will overwrite the manual work**. The list of those manual changes
is in the header of the script itself. The tuning went in two rounds, on
10.08.2026. and 11.08.2026., the second of which moved 59 designators. After such
an edit, run **only** `regen_outputs.ps1`, because `route_board.ps1` calls that
script at the end and puts the designators back where it computed them.

The board legend is two lines, `OBD-II SIMULATOR v0.7` and
`Designed by Filip Raic`, on both sides. Its space is reserved in the packer
before parts start to be placed, otherwise the first part landing in that band
pushes the legend into a corner.

## A fixed generator bug: the module outline

On the first routed version resistor R25 stood **under the module PCB of U6**, in
the corner by the antenna. The cause was not the placement but the generator:
`build_board.py` redrew the module's courtyard around the **bounding box of the
pads**, and the antenna end of the module has no pads at all. The courtyard came
out 6,5 mm shorter than the module itself:

| | x range |
|---|---|
| Courtyard the script drew | 24,50 .. **44,26** |
| The actual module body (F.Fab) | 25,25 .. **50,75** |

To the packer that piece of the module looked like empty space. **DRC did not
report it**, because DRC compares courtyards and the courtyard was too short. The
real outline from the F.Fab layer is used now, and R25 sits **19,9 mm from the
module body**.

A second bug was fixed along the way: the first version of the fix computed the
bounding box through `BOX2I.Merge`, which gave **a different result on two
consecutive runs**, because `GetBoundingBox()` through SWIG returns a temporary
that does not survive the next call. Every bounding box is now converted to plain
numbers immediately.

## Frozen placement: why there is none at the moment

`kicad/scripts/placement_locked.py` can hold the coordinates of every part and
thereby make regeneration repeatable. It is **empty** at the moment, so the
packer computes the placement.

The reason is that the freeze was made while the board was 115 x 100 mm and the
packer was overloaded, and it cemented exactly what the review calls out as bad:
bootstrap capacitors 14 to 16 mm from their pins, C7 seventeen millimetres from
OSC2, the ESD diode nineteen millimetres behind the OBD connector. The intent
behind `NEAR_OF` in `build_board.py` was the opposite, but `LOCKED` overrode
`NEAR_OF`.

At 130 x 115 mm the packer has room, so `NEAR_OF` decides again. If a placement
is ever settled and worth freezing, the coordinates are dumped from the finished
board and put back into that file.

On how sensitive the packer is, a warning from practice: introducing **one single
resistor** (R17B) produced three different collapses in three attempts, the worst
of which broke nine nets, because it pushed one capacitor into the corridor
carrying SPI and all three button lines.

---

# How the board is generated

The whole chain (placement, CAN pair, routing, ground repair, DRC):

```powershell
powershell -ExecutionPolicy Bypass -File kicad\scripts\route_board.ps1
```

Derived files only (renders, gerbers, drawing, schematics, HTML), without
re-routing:

```powershell
powershell -ExecutionPolicy Bypass -File kicad\scripts\regen_outputs.ps1
```

**Neither script is optional after a board change.** Both renders are embedded
in this README, so anything that changes the board and is not followed by
`regen_outputs.ps1` leaves a picture on GitHub that shows a board nobody has.
A re-route changes both sides, a silkscreen edit changes only the top one, and
in both cases the fix is the same single command.

Routing is **not deterministic** in the sense of "the same outcome in all 10
runs": Freerouting produces the same track layout, but the ground repair depends
on how the pour fell apart, so the number of repair rounds varies.

## The steps in the chain and why each exists

| Script | What it does | Why |
|---|---|---|
| `build_board.py` | builds the whole board from nothing: nets, footprints, placement, zones, silkscreen | the single source of truth for the board. Anything done by hand in KiCad disappears on the next run |
| `route_can_chain.py` | routes the CAN pair as a chain, before Freerouting, on the top layer, without vias, and restores it after the SES import (`--replay`) | Freerouting routes a minimal tree. It does not rip up protected tracks (`(type protect)`), but it lays its own trace alongside them, which left CANH with 42 segments and 19 branch points |
| `dsn_export.py` | export to Specctra DSN, keeping the CAN pair as an immovable obstacle | the router has to route around the chain, not through it |
| `ses_import.py` | import the result, thermal vias under exposed pads, bridging of ground islands | the Specctra export throws away all copper, so everything that is not a track is made here |
| `route_one_net.py` | a small maze router for a single net | at this density Freerouting occasionally leaves one net unconnected |
| `heal_gnd_fragments.py` | joins fragments of the ground pour | B.Cu tracks cut the pour into islands, and which pad ends up cut off changes with every placement |
| `stitch_gnd_pad.py` | stitches a single ground pad onto the main pour | pad 1 of module U6 has a 1,2 mm stub and the via at its end fell into an island |
| `dedup_vias.py` | deletes overlapping vias and duplicated segments | two rounds of ground repair can pick the same point, and DRC then reports a hole spacing of 0,0000 mm |
| `clean_dangling.py` | removes dead track and via leftovers | a leftover leading nowhere is reported by DRC as an unconnected item |
| `place_silk_after_route.py` | moves the designators now that the copper is known | before routing, designators can dodge pads only, not tracks |

Deleting the pin list of the CAN nets in the DSN was tried and rejected. The idea
was that a net with no pins has nothing to connect, so the router would not add
its own trace. The effect was the opposite: 91 segments on CANH and 37 unconnected
items across the board. The reasoning is recorded in `dsn_export.py` so that it is
not attempted again.

## What routing this board taught

- The placement is on a knife's edge. Moving one resistor by 2 mm can break five
  nets, and moving one capacitor broke nine. If something has to move, move the
  NEW part, not its neighbours.
- An 8-pin header lying flat next to the module acts as a wall of THT pads and
  closes the exit for every signal behind it.
- Test points in a tidy row along the edge are a mistake. CANH grew from 62 to
  148 mm and MOSI from 100 to 148 mm, because every net then has to go down to
  the bottom of the board and come back.
- The crystal capacitors anchor to the **crystal**, not to the OSC pins.
  Anchoring to the OSC pins was tried and rejected: the capacitors get pushed
  into the corridor the button lines leave through, and all three button nets
  stay unrouted in all 10 runs.

---

# What is NOT solved

- **The USB pairs are not length-matched.** The USB-A pair is 23,2 and 15,0 mm
  without a single via, a difference of 8,2 mm, and the USB-C pair is 131,9 and
  137,8 mm with two and three vias respectively. Unlike the CAN pair, these are
  **not** routed by a script of their own: they cross the whole board and have no
  path on the top layer, so trying to route them without vias would only make
  them longer. This is the limit of a machine-routed two-layer board, not an
  oversight.
- **The length difference of the CAN pair is about 20 mm** and cannot get smaller
  without moving parts. The reasoning is above, in the section on the CAN chain.
- **The decoupling capacitors of U5 and U11 miss the 6 mm target** (9,0 and
  11,7 mm to the nearest 100 nF). The power zone became tighter once the
  capacitor and inductor footprints grew.
- **The feedback divider is not right at the pin.** R16 is 19,6 mm from the FB
  pin and R24 16,4 mm (measured 10.08.2026., after the move to a radial inductor,
  before that 17,8 and 16,1 mm). The FB node itself is short because the members
  are chained (R17A is 4,0 mm from R16), but the first member could not reach the
  pin. The cause is physical: a horizontal resistor is 12,3 mm long, and nine
  parts compete around one SOT-23.
- **The crystal capacitors are 12,0 and 11,4 mm from the OSC pins.** Anchoring to
  the OSC pins was tried and rejected, see above.
- **The criterion "termination and ESD no more than 5 mm from the connector" is
  not achievable.** The J1962F body is 43,3 x 20,7 mm and the contacts are inside
  it: pin 14 is 6,3 mm from the lower edge of the housing, pin 6 as much as
  14,9 mm. Nothing can be placed inside the body. The criterion was written while
  J2 was a pin header leading to a connector on the front panel. The realistic
  criterion is "immediately outside the connector body, where the pair comes
  out", and that has been met.
- **The board still needs a 12 V PD source for full function.** On an ordinary PC
  USB port the CH224K does not negotiate 12 V, so U11 cannot make 5 V (it needs
  an input above 5 / 0,75 = 6,7 V) and the USB-A host is dead. The 3,3 V rail
  works, because its minimum input is 4,5 V. This is a known limit of the
  architecture, not a fault.

---

# Must be checked before ordering

The full list is in
[`kicad/PRE-FABRICATION-CHECKLIST.md`](kicad/PRE-FABRICATION-CHECKLIST.md), and
it opens with the one item that is no longer a question:

- **The footprint of SW6 is wrong, and this is the known bug of revision v0.7.**
  Pad 2 of `SKRHABE010.kicad_mod` is not the centre contact but the common one,
  which is why four of the five directions did not work on the first assembled
  board. It is worked around in the firmware. In the next revision pad 2 goes to
  ground and the centre to the microcontroller input. Read section 0 of the
  checklist before ordering.

The rest of the list still has to be walked, and these must not be skipped under
any circumstances:

- **The lead pitch of the EN11-HSB1AQ20, with calipers.** The footprint assumes
  the 11 mm family standard. It is the only footprint on the board that was not
  measured from the delivered part.
- **The direction of rotation of the encoder.** Which channel leads clockwise
  depends on the orientation of the part and is established with an ohmmeter or
  on the assembled board. Swapping A and B is a constant in the firmware.
- **The pin numbering of the J1962F connector**, compared against the numbers
  moulded into the plastic of the delivered part.
- **The pinout of the PESD1CAN (D1)** on the actual part.

## A note on flash U7

Schematic 3: ESP32-S3-WROOM-1, external flash and USB subsystem

The flash is the third load on the SPI bus in that figure, alongside the MCP2515
and the display, which is what the series termination and the separate chip
select lines are for.

The part actually ordered is an **Infineon S25FL128LAGMFM010** (package SOC008,
SOIC-8 208 mil), so that is also the value of the footprint. The Winbond
W25Q128JVSIQ is an equivalent replacement: the same package, the same pinout and
the same command set that the driver uses. The narrower 3,9 mm (150 mil)
footprint fits **neither of them**.

## A note on the thermal pad of the module

The module's EPAD (pad 41 in the footprint) is a thermal pad connected to ground.
The module also has ground on pins 1 and 40, so the board works without the EPAD
being soldered and it may safely be left unsoldered. Soldering it with a hand
iron is not feasible, since the pad is underneath the module housing. The claim
that the EPAD can be soldered through the vias from the bottom side **does not
hold** for this footprint: those vias have a mask opening on the top side only,
so they are covered by mask from below and there is nowhere to push solder
through.

Those twelve vias were widened from **0,20 to 0,30 mm** on 11.08.2026., because
they were the only holes on the board below 0,30 mm and on their own pushed a
JLCPCB order into the more expensive fine-drill class. The pad stayed at 0,60 mm,
the annular ring is 0,15 mm and the board was not re-routed. The reasoning and
the numbers are in `gerber/README.md`. An earlier version of this section also
cited the 0,2 mm drill as a second argument against soldering through the vias -
that argument no longer holds, but the mask on the bottom side still does and is
enough on its own.

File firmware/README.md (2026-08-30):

# OBD-II Simulator - firmware

PlatformIO project for the simulator device. The portable
protocol core lives one directory up (`../include`, `../src`) and is compiled
into every environment by `import_core.py`. This project adds the hardware
layers on top of the core's four `extern` platform hooks.

Wiki page for this part of the project, **Firmware**, on the repository wiki. It covers
the same ground for someone who is not reading the source: installing
PlatformIO, the module layout, the request path and how to run the tests.

## Invoking PlatformIO

If PlatformIO was installed with pip rather than as a standalone binary, call it
as a module:

```sh
python -m platformio run -e custom-board
```

Two failure modes worth knowing, because neither says what is wrong:

- **On Windows, `python` may resolve to the Microsoft Store alias**, which
  prints "Python was not found" and does nothing else. Point at the real
  interpreter if that happens.
- **The `native` environment needs a host C++ compiler on `PATH`.** Without one
  the build fails with exit code 1 and no error output at all, so check that
  before looking anywhere else.

## Environments

| env | Target | Notes |
|-----|---|---|
| `custom-board` | ESP32-S3-WROOM-1, both on the breadboard adapter and on the dedicated PCB | pins in `include/pins_custom_s3.h`. Flashes over USB-C through the chip's own USB-Serial-JTAG |
| `custom-board-bringup` | the same board, flashed over the UART header J6 | identical firmware, different upload path. Used when the USB-C path is unavailable or when the panic text has to be read, see [`tools/README.md`](tools/README.md) |
| `native` | Development host | runs `../tests/test_simulator.cpp`, no hardware |

```sh
pio run  -e custom-board -t upload  # build + flash the board
pio device monitor              # serial log, 115200 baud
pio test -e native              # host-side protocol tests (98 cases)
```

## Layout

| Path | Module |
|---|---|
| `src/hal/` | shared-SPI mutex (five peripherals, two tasks), `millis` shim |
| `src/can/` | MCP2515 driver (500 kbit/s @ 8 MHz, filters 0x7DF/0x7E0), CAN task, ISO-TP flow-control hook |
| `src/app/` | command/snapshot contracts between the two FreeRTOS tasks |
| `src/ui/` | input (EN11 incremental encoder with push, joystick, CONFIRM/CLEAR/RETURN), screen stack, four screens |
| `src/storage/` | FAT filesystem on S25FL128L (FatFs custom diskio), USB-C MSC device mode, USB-A stick import/export (v0.5) |
| `include/` | board pin maps, sensor metadata, DTC string codec |

## Architecture

Schematic 3: ESP32-S3-WROOM-1, external flash and USB subsystem

The hardware this code drives: one SPI bus with three chip selects (MCP2515,
display, flash U7), the interrupt line from the CAN controller, and the single
USB OTG controller that the TS3USB221 mux switches between the USB-C and the
USB-A port. The pin numbers in the figure are the ones in
`include/pins_custom_s3.h`, and the rest of the board is drawn in
[`../hardware/README.md`](../hardware/README.md).

Two FreeRTOS tasks: the high-priority **CAN task** (core 1) owns
all simulator state, answers OBD requests through the protocol core and
republishes a state snapshot at 10 Hz. The low-priority **UI task** (core 0)
renders the ILI9341 and turns the physical controls into `InputEvent`s.
The UI mutates state only through the `app::Command` queue - no unsynchronized
shared state. Every SPI access (CAN, TFT, SD, external flash) runs under the
recursive HAL mutex.

## Scenarios and USB (v0.5)

Stored as JSON in `/flash/scenarios/*.json` on the S25FL128L FAT filesystem
and the last-used scenario is reloaded on boot. The factory
scenario is compiled in (matching `DtcBank::load_defaults()`), with an
optional `/flash/factory.json` override. The scenario `vin` is shown in the UI **and**
answered over the bus: loading a scenario passes it to the core's
`obd_set_vin()`. A missing or empty key restores the default `OBD_VIN`.

The dedicated board has one USB OTG controller switched by a TS3USB221 mux:

- **PC link (MSC)** - Settings action reboots into a boot mode where the
  whole flash filesystem is exposed over USB-C as a USB disk
  (`usb_msc_device.cpp`). RETURN reboots back.
- **USB-A stick** - Settings actions import/export scenario JSON files
  to/from a stick via a minimal MSC BOT/SCSI host driver
  (`usb_stick.cpp`). *Compile-verified only - not yet exercised on
  hardware.*

The breadboard development setup has no USB subsystem and no S25FL128L, so it
runs with the compiled-in factory scenario and inert USB rows.

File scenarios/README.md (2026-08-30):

# Example simulation scenarios

JSON scenarios in the format the firmware loads from `/flash/scenarios` on
the on-board 16 MB SPI NOR FAT filesystem (v0.5).
Copy them onto the device over the USB-C PC link (the device shows up as a
USB disk) or import them from a USB stick via Settings. Edit values freely,
they are clamped to each sensor's valid range on load.

- `sensors` keys are the named identifiers from
  `firmware/include/sensor_meta.h` (e.g. `coolant_temp_c`, `rpm`,
  `vehicle_speed_kmh`), and values are physical units.
- `dtcs[].state` is `"pending"` or `"confirmed"`. Any confirmed DTC turns the
  MIL on, so `mil_on` is informative only.
- `vin` is both shown in the UI and reported over the bus: loading a scenario
  passes it to `obd_set_vin()`, so mode 0x09 answers with it. Omit the key, or
  set it to an empty string, and the default `WVWZZZ1KZAW000001` applies.

Wiki page: **Usage**, on the repository wiki.

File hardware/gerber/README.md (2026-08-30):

# Gerber and drill files

The ordering procedure written for a first-time builder is on the **Building the
device** page of the repository wiki.
These files are regenerated by
[`../kicad/scripts/regen_outputs.ps1`](../kicad/scripts/README.md), never
exported by hand.

Fabrication files for the dedicated board, **revision v0.7**, two-layer FR4,
**130 x 115 mm**, exported from `../kicad/obd2-simulator.kicad_pcb`
(KiCad 10, `kicad-cli`). Last export: 11.08.2026.

Board state at that export: 107 footprints, 64 nets including ground, 892 track
segments, 73 vias, DRC clean with nothing unconnected. The drill file holds
**326 holes** in total. The smallest hole is **0,30 mm** (93 of them, 72 vias
and 21 holes inside footprints), and copper clearance sits exactly on the
0,150 mm rule everywhere.

The vias are not all alike: 72 are 0,60 / 0,30 mm and one is 0,80 / 0,40 mm, on
net V5_STICK, because that net belongs to the `Power` class.

## Why no hole on the board is smaller than 0,30 mm

Until 11.08.2026. there were twelve of them, **0,20 mm** across, all in the same
place: thermal vias under pad 41 (EPAD) of the U6 module footprint. They were
not chosen but inherited, because KiCad's `ESP32-S3-WROOM-1` footprint ships
that way. They are the reason the project's `min_through_hole_diameter` rule
stood at 0,20 mm.

Those holes were widened to 0,30 mm, because JLCPCB bills a drill under 0,30 mm
as an advanced parameter and they were the only item pushing the order into that
class. The change makes nothing worse:

| Item | Before | After | Limit |
|---|---|---|---|
| Hole | 0,20 mm | 0,30 mm | 0,30 mm standard |
| Pad | 0,60 mm | 0,60 mm, unchanged | - |
| Annular ring | 0,20 mm | 0,15 mm | 0,13 mm |
| Edge-to-edge gap between neighbouring holes in the grid | 0,79 mm | 0,69 mm | 0,25 mm (board rule) |

Thermally it is an improvement, since a wider wall means more copper between the
module pad and the ground pour. No pad moved, so the board was not re-routed:
the hole size was changed directly in the `.kicad_pcb`, and DRC still reports 0
errors and 0 unconnected items. To stop the library footprint from slipping back
in, `build_board.py` now raises every hole of every loaded footprint to
`MIN_DRILL_MM = 0,3`, and the design rule stands at the same value.

## Hole-to-hole spacing is under 0,50 mm, and across different nets

Worth knowing **before** picking a fabricator. In its standard two-layer process
JLCPCB asks for 0,50 mm between holes belonging to different nets. The board
does not meet that, measured on 10.08.2026. by running DRC with the rule raised
to 0,50 mm:

| Pair | Spacing | Nets |
|---|---|---|
| 15 pairs inside footprint J1 (USB-C) | **0,450 mm** (14 at 0,4500 and one at 0,4524) | different (GND, VBUS, CC, D+, D-) |
| vias `RXD0` and `TXD0` | **0,4694 mm** | different |
| 6 thermal vias under the exposed pad of U1 | 0,400 mm | same (ground) |

Twenty-two pairs in total. The measurement was repeated on 11.08.2026., after
the vias under module U6 were widened to 0,30 mm, and produced an **identical
list**. Drill diameter and hole spacing are two independent parameters and have
to be checked separately when ordering.

Those 15 pairs come from **the official footprint itself**,
`USB_C_Receptacle_GCT_USB4085`, so that is the geometry of the connector and
cannot be fixed without changing the part. The board therefore needs a
fabricator who accepts 0,45 mm anyway, and one who does also passes the via pair
at 0,466 mm. Check that when ordering, or ask up front.

Note: DRC against the project rules reports 0 errors because the project rule is
set to 0,25 mm. That is not an oversight but a consequence of the connector
footprint being what it is.

## The package to upload

**`obd2-simulator-v07-for-fabrication.zip`** is what goes to the fabricator's web
form. It holds exactly nine fabrication files, without the auxiliary layers
(Courtyard, Fab, Adhesive, Margin, User_*, Eco, Comments, Drawings), because
some readers pick those up as extra copper or as an outline.

It is built by `../kicad/scripts/make_fab_zip.py`, and `regen_outputs.ps1`
refreshes it together with the other derived files.

The paste layers are deliberately left out: the board is hand-soldered and no
steel stencil is ordered. If one is ever needed, add `F_Paste.gtp` and
`B_Paste.gbp`.

The ordering procedure, the parameters to enter and the checks to run before
uploading are described in chapter 1 of the technical documentation.

| File | Layer |
|---|---|
| `obd2-simulator-F_Cu.gtl` | copper, top layer |
| `obd2-simulator-B_Cu.gbl` | copper, bottom layer (GND pour) |
| `obd2-simulator-F_Mask.gts` / `B_Mask.gbs` | solder mask |
| `obd2-simulator-F_Paste.gtp` / `B_Paste.gbp` | paste (SMD stencil) |
| `obd2-simulator-F_Silkscreen.gto` / `B_Silkscreen.gbo` | silkscreen |
| `obd2-simulator-Edge_Cuts.gm1` | board outline |
| `obd2-simulator.drl` | drill (Excellon) |
| `obd2-simulator-job.gbrjob` | Gerber job file |

> **Before ordering fabrication** read `../README.md` and
> `../kicad/PRE-FABRICATION-CHECKLIST.md`: the custom footprints (CH224K,
> SKRHABE010, SEP-A-OBD-D2, EN11-HSB1AQ20) and the mechanical fit of the
> connectors are verified against the parts as delivered. Re-export the files
> after those checks.
>
> Note: the paste layer (`F_Paste`) now covers the integrated circuits only,
> since every passive is through-hole, so a stencil is worth ordering only if
> the ICs are to be paste-soldered.

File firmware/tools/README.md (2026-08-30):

# Bring-up tools

Helpers used while putting the assembled v0.7 board into service. Nothing here
is part of the shipped firmware.

The ordinary way to flash the board is the one on the **Firmware** page of the
repository wiki, over USB-C with PlatformIO. Everything in this directory exists for when that path is
unavailable or when it does not say enough.

| Item | What it is | When it is used |
|---|---|---|
| `elm327/` | Fifteen scripts that drive a commercial ELM327 adapter against the simulator and print what comes back, from a one-line link check to the response-time and throughput measurements. How the test cases were executed on the assembled board. Has its own [`README.md`](elm327/README.md) | after the board answers at all, to prove that it answers *correctly* |
| `flash_jtag.py` | Flashes over USB-C without letting esptool reconfigure the port. On USB-Serial-JTAG the DTR and RTS lines drive the internal reset and IO0, and esptool's own open sequence knocks the chip back out of download mode | whenever the USB-C path is the one in use. See the last section of this file |
| `capture_boot.py` | Waits for the board's USB CDC port to appear and logs everything it says, reopening the port as often as needed | run it **first**, then power-cycle. A chip rebooting in a loop is captured too, which a plain monitor misses |

The rule for all three: **one entry into download mode, one port session.**
Closing the port makes Windows drop DTR and RTS, which on USB-Serial-JTAG costs
another entry by hand, so a stray `device list` is not free.

## Why go through J6 at all

The board can be flashed over USB-C through the ESP32-S3's own USB-Serial-JTAG,
and that is the documented path in `platformio.ini`. During bring-up two things
made it a poor place to stand:

1. **The panic text never arrives.** The Arduino ESP32 SDK sets
   `CONFIG_ESP_CONSOLE_UART_DEFAULT=y` with USB-Serial-JTAG only as the
   *secondary* console. The panic handler writes to the **primary** one, so the
   Guru Meditation line and the backtrace go out on UART0, header J6. Over
   USB-C only whatever fits the 64-byte FIFO between host polls survives, which
   is how a boot log ends in a meaningless fragment like `fcebc50`.
   (`src/hal/crash_report.cpp` is the other half of the answer: it reads the
   core dump back out of flash on the next boot, and needs no adapter.)
2. **The USB-C data path is currently a bodge.** Until U9 is fitted, D+ and D-
   run over flying wires and the link corrupts the occasional byte, which turns
   every flash attempt into a coin flip.

J6 sidesteps both. It carries `TXD0`, `RXD0` and `GND` and nothing else.

## Pinout of J6

| Pin | Net | GPIO | Direction |
|---|---|---|---|
| 1 (square pad) | `TXD0` | 43 | board → PC |
| 2 | `RXD0` | 44 | PC → board |
| 3 | `GND` | - | - |

Any USB-serial converter will do: a CP2102, a CH340, an FT232 module, or a
spare microcontroller board running a pass-through sketch. Wire it straight
across, converter RX to J6 pin 1, converter TX to J6 pin 2, grounds together.

**Check the converter's logic level first.** The ESP32-S3 is a 3,3 V part and
pin 2 is an input into it, so a 5 V converter needs a divider on that line, or
a converter with a 3,3 V / 5 V switch set to 3,3 V. Pin 1 is an output from the
board and is safe either way, since a 5 V receiver reads 3,3 V as a high. Many
cheap modules are labelled 3,3 V but drive 5 V on TX, so measure it rather than
trusting the silkscreen.

## Entering download mode

J6 has no DTR and no RTS, so nothing can put the chip into download mode for
you. By hand, in order of reliability:

1. **Power-up entry (best).** Unplug USB-C, wait 5 s, hold **BOOT (SW4)**, plug
   USB-C back in, count to two, release BOOT. The IO0 level is sampled at
   startup, so this cannot miss the moment.
2. **Button entry.** Hold **BOOT (SW4)**, tap **RESET (SW5)**, release BOOT.

The board stays in download mode until it is reset, so there is no rush.

## Flashing over J6

From `firmware/`, with `COMx` being the **converter's** port, not the board's:

```
python -m platformio run -e custom-board-bringup -t upload --upload-port COMx
```

`--before default_reset` and `--after hard_reset` are harmless here: they toggle
DTR and RTS, which a plain three-wire connection does not carry. Reset the
board by hand
afterwards, or just power-cycle it.

If PlatformIO's own reset handling gets in the way, esptool does the same job
directly:

```
python -m esptool --chip esp32s3 --port COMx --baud 115200 \
    --before no_reset --after no_reset write_flash -z \
    0x0     .pio/build/custom-board-bringup/bootloader.bin \
    0x8000  .pio/build/custom-board-bringup/partitions.bin \
    0x10000 .pio/build/custom-board-bringup/firmware.bin
```

Then the console, on the same port:

```
python -m platformio device monitor -p COMx -b 115200
```

## Flashing over USB-C instead

If the USB-C path is the one in use, the wrapper that works around esptool's
handling of USB-Serial-JTAG on Windows is `flash_jtag.py`, described in the
commissioning note. Its rule is absolute: **one entry into download mode, one
port session.** Closing the port makes Windows drop DTR and RTS, and on
USB-Serial-JTAG those drive the internal reset and IO0, so every stray
`device list` or connection check costs another entry by hand.

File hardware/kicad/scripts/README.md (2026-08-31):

# Board scripts

The board is **generated, not drawn**. There is no `.kicad_sch` in this project
and the `.kicad_pcb` is an output, so everything about the board that is a
decision lives in these scripts. Anything adjusted by hand in KiCad disappears
the next time `build_board.py` runs, with one deliberate exception noted below.

Wiki page for the hardware: **Building the device**, on the repository wiki.
The design reasoning behind the board is in [`../../README.md`](../../README.md).
The "if you change X, check Y" table lives in the project's working notes
(`docs/MAPA-POVEZANIH-DATOTEKA.md`), which are Croatian and not part of this
repository.

## The interpreter these scripts need

Almost every script here imports `pcbnew`, which only exists inside KiCad's own
Python. It is not the `python` on PATH:

```powershell
& "$env:LOCALAPPDATA\Programs\KiCad\10.0\bin\python.exe" build_board.py board.kicad_pcb
```

The two PowerShell entry points set that up themselves, so calling them needs
nothing but PowerShell. `make_fab_zip.py` and the `docx/` tools are the
exceptions: they touch no board object and run on any Python 3.

## The two entry points

Everything else in this directory is called by one of these two, or is run by
hand for a one-off job.

| Run this | When | What it does |
|---|---|---|
| `route_board.ps1` | a part, a net, a value or the placement changed | Rebuilds the board from nothing and routes it: `build_board.py` → CAN chain → Freerouting (up to 10 attempts, best one kept) → ground repair → DRC. Takes minutes and **throws away the hand-tuned silkscreen** |
| `regen_outputs.ps1` | the board file is already right and the derived files are stale | Touches no placement and no routing. Re-exports renders, gerbers, the fabrication zip, the dimensioned drawing, the interactive HTML view and the schematics |

```powershell
powershell -ExecutionPolicy Bypass -File route_board.ps1
powershell -ExecutionPolicy Bypass -File regen_outputs.ps1
```

> **Do not reach for `route_board.ps1` by reflex.** It ends by calling
> `place_silk_after_route.py`, which puts all 103 reference designators back on
> computed coordinates. Two rounds of hand-tuning (10.08. and 11.08.2026., 59
> designators in the second) live in the `.kicad_pcb` and nowhere else. If
> nothing moved on the copper, edit the `.kicad_pcb` directly, run DRC, and then
> run **only** `regen_outputs.ps1`. Mirror that same edit back into
> `build_board.py`, or the next full regeneration undoes it.

## What `route_board.ps1` runs, in order

Each of these has a "why it exists" header of its own. The short version:

| Step | Script | Why it is a separate step |
|---|---|---|
| 1 | `build_board.py` | The single source of truth: nets, footprints, placement, zones, silkscreen. Aborts the chain on failure, so a stale board is never routed |
| 2 | `route_can_chain.py` | Routes the CAN pair as a chain first, while the board is empty. Freerouting routes a minimal tree and knows nothing about the required transceiver → termination → ESD → connector order |
| 3 | `dsn_export.py` | Specctra export, with the CAN pair handed over as a fixed obstacle |
| 4 | `tools/freerouting.jar` | The autorouter. Randomised, so it runs up to ten times and the best attempt wins |
| 5 | `ses_import.py` | Imports the result and rebuilds everything the Specctra round-trip discards: thermal vias, pours, island bridging |
| 6 | `route_can_chain.py --replay` | Restores the chain, because the router lays its own trace alongside a protected one |
| 7 | `route_one_net.py` | A small maze router for the one net Freerouting occasionally leaves open |
| 8 | `heal_gnd_fragments.py`, `stitch_gnd_pad.py` | Bottom-layer tracks cut the ground pour into islands. Which pad ends up cut off changes with every placement |
| 9 | `dedup_vias.py`, `clean_dangling.py` | Two repair rounds can pick the same point, and a dead stub reads to DRC as an unconnected item |
| 10 | `place_silk_after_route.py` | Designators can only dodge tracks once the copper exists |

The chain is **not** reproducible run for run. Freerouting gives the same track
layout, but the number of ground-repair rounds depends on how the pour fell
apart, so via and segment counts move. Every number quoted anywhere about this
board is therefore re-measured from the `.kicad_pcb`, never carried over from an
earlier version of a text.

## What `regen_outputs.ps1` writes, and where

Three destinations, and the split is deliberate: the repository is in English
and public, the written documentation is in Croatian and private, the website is
neither.

| Output | Destination | Note |
|---|---|---|
| `render-top.png`, `render-bottom.png` | `../` (`hardware/kicad/`) | `kicad-cli pcb render`. Both are embedded in `hardware/README.md` and the top one is a documentation figure, so they have to be regenerated with every board or routing change |
| Gerbers, Excellon drill, gbrjob | `../../gerber/` | see [`../../gerber/README.md`](../../gerber/README.md) |
| `obd2-simulator-v07-for-fabrication.zip` | `../../gerber/` | `make_fab_zip.py`, exactly nine production layers and no auxiliary ones |
| `schema1-4.svg`, `blok.svg`, `canchain.svg` | `../../` (`hardware/`) | `generate_figures.py`, English. The only schematics a GitHub visitor gets |
| `fig/zones.svg`, `fig/nets.svg`, `fig/ip2368.svg` | `fig/` | tracked in git since 30.08.2026. and embedded in `hardware/README.md` |
| `tehnicki-crtez-pcb-v07.svg` / `.png` | `../../../../Pisani dio/Slike za rad/crtezi-ploce/` | `generate_drawing.py`, Croatian, a documentation figure. **Outside the repository** |
| `OBD2-board-v0.7/index.html` | `../../../../Website and GitHub/` | `generate_pcb_html.py`. **Outside the repository**, and never edited by hand |

Two traps worth knowing before running it:

- **The PNG of the dimensioned drawing is rasterised by headless Chrome**, at a
  scale factor picked to land on the size the documentation was laid out around.
  If Chrome is missing the script says so and leaves the old PNG in place, which
  is how a stale drawing once survived a regeneration.
- **The interactive HTML view is generated, so a hand edit vanishes.** Its text
  is edited in `generate_pcb_html.py`: English in the template beside its
  `data-i18n` key, Croatian in the `HR` dictionary in the same template. Its
  final line prints the number of tracks, vias and footprints it drew (892, 73,
  103). If those differ from the numbers in `hardware/README.md`, the board was
  regenerated and the text was not.

## Run by hand, not part of either chain

| Script | When |
|---|---|
| `generate_figures.py` | a schematic changed. It draws **by hand**, not from the board, so it never follows a board change on its own. `--lang hr` still works and nothing calls it |
| `generate_drawing.py` | the outline or a footprint position changed. Compare the result against `../render-top.png`, which is the same board and the only quick way to see whether the layout is right |
| `generate_pcb_html.py` | only that page needs refreshing, without the rest of a regeneration |
| `gen_3dmodels.py` | a custom VRML model changed. Two parts have no model in KiCad's library |
| `apply_3dmodels.py` | only the models changed. It attaches them to the **already routed** board, so the routing survives |
| `route_one_net.py`, `stitch_gnd_pad.py` | finishing one specific net or pad on a board that is otherwise done |
| `make_fab_zip.py` | repacking the fabricator's zip on its own |

## Modules, not scripts

`place.py` (the shelf packer), `models3d.py` (the list of models to attach by
hand) and `placement_locked.py` (frozen coordinates, **currently empty on
purpose**, see `hardware/README.md`) are imported by the generators. Running
them does nothing.

## Subdirectories

| Path | What it is |
|---|---|
| `fig/` | every figure `generate_figures.py` draws. Six are copied up into `hardware/`, three are used from here |
| `docx/` | `.docx` tooling for a machine with no Word. Has its own [`README.md`](docx/README.md) |
| `../tools/` | where `freerouting.jar` goes. Not in the repository, see [`../tools/README.md`](../tools/README.md) |
| `../footprints/obd2.pretty/` | the four custom footprints: CH224K, SEP-A-OBD-D2, SKRHABE010, RK12L12C0A0G |

## Before ordering fabrication

[`../PRE-FABRICATION-CHECKLIST.md`](../PRE-FABRICATION-CHECKLIST.md), without
exception. The custom footprints above were drawn from datasheets, and the
checklist is what catches the one that is wrong.

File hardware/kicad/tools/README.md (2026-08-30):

# Router

`route_board.ps1` hands the board to **Freerouting**, an external autorouter, and
imports the result back. The jar is not in this repository: it is 58 MB of
third-party build output, which has no business in the history of a project this
size.

## Getting it

Download a release jar from the project and drop it here as
`freerouting.jar`:

    https://github.com/freerouting/freerouting/releases

The file the board was routed with is not a tagged release but a build of
**2026-05-13**, revision `20f1a72e`, built with Adoptium 25. Any release from
that period or later behaves the same for this board. The routing chain calls it
head-on, so only the file name matters:

    java -jar tools/freerouting.jar -de board.dsn -do result.ses -mp 300

A Java runtime of 21 or newer is required. `route_board.ps1` looks for `java` on
PATH and falls back to the JetBrains runtime bundled with CLion.

## Why the result is not deterministic

The router is randomised, so two runs on the same input give different track
counts and a different number of vias. `route_board.ps1` therefore runs it up to
ten times and keeps the best attempt, judged by unrouted nets first and via
count second. That is also why any number quoted about the layout - 738 segments,
60 vias - belongs to one specific run and is re-measured from the board file
rather than carried over from an earlier text.

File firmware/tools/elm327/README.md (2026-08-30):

# ELM327 test tools

Scripts that drive a commercial ELM327 diagnostic adapter against the simulator
and print what comes back. They are how the test cases were
actually executed on the assembled v0.7 board on 22.08.2026.

Nothing here is part of the firmware, and nothing here talks to the board
directly. The only link is the OBD-II connector: the PC drives the adapter, the
adapter drives the CAN bus, the simulator answers. That matters, because the
board's own USB path does not work on the first assembled unit, so no counter
inside the firmware can be read out and no instrumented build can be flashed.
Everything below therefore measures the device the way a workshop would.

## Requirements

- An ELM327 adapter, USB or Bluetooth. A Bluetooth one pairs as an **outgoing**
  COM port. Windows creates two ports per pairing, incoming and outgoing, and
  only the outgoing one reaches the adapter.
- `pyserial`. Nothing else.
- The adapter powers itself from pin 16 of the connector, so the board has to be
  running before the adapter can even be paired.

Every script takes the port as its first argument and falls back to `COM5`:

```
python check_link.py COM7
```

## Before measuring anything

1. Power the board from a USB-C charger whose label **explicitly lists 12 V**.
   A charger without that profile leaves the board on 9 V or 5 V, where it
   resets periodically.
2. Check that the home screen says `CAN OK`.
3. Plug the adapter in and let the link come up.
4. For anything that compares values against the screen, switch the device to
   the **Manual** profile. In Idle the simulation model rewrites 11 of the 21
   parameters every 100 ms.

## The scripts

| Script | What it does | Test case |
|---|---|---|
| `elm327.py` | Shared library: adapter client, ISO-TP payload assembly, PID and DTC decoding, the 21-parameter table | - |
| `check_link.py` | Adapter version, negotiated protocol, supported-PID mask against what the protocol core builds | T-01 |
| `service_tests.py` | Supported-PID masks, reference trace, pending DTCs, VIN, unsupported mode. Writes `service_tests.txt` | T-01, T-05, T-07, T-08 |
| `read_sensors.py` | All 21 parameters decoded, formatted for line-by-line comparison with the sensor screen | T-02 |
| `read_dtcs.py` | MIL state, confirmed list, pending list. Run it after each step while walking a code up and down on the device | T-04 |
| `clear_dtcs.py` | Mode 0x04, then proof the bank is empty and the MIL is off. Also shows silence versus negative response | T-06 |
| `freeze_frame.py` | Live values against the frozen snapshot | T-09 |
| `soak_test.py` | Eight parameters in a loop for half an hour, counting lost responses and dropped links. Writes `soak_test.txt` | T-03 |
| `reconnect_test.py` | Watches the link fall and return while the tool is unplugged and plugged back in. Writes `reconnect_test.txt` | T-10 |
| `response_time.py` | Upper bound on the response time by tightening the adapter's own timeout. Writes `response_time.txt` | NZ-5 |
| `throughput.py` | Requests per second, bounded by the adapter rather than the device | - |
| `bus_traffic.py` | Keeps the bus busy while something else is being measured | T-11 and any bench measurement |
| `profile_check.py` | Proves the Manual profile freezes the values | - |

## Order that works

```
python check_link.py            # link is up, mask matches the core
python service_tests.py         # T-01, T-05, T-07, T-08 and the reference trace
python read_sensors.py          # T-02, compare against the screen, Manual profile
python read_dtcs.py             # T-04, once per step while walking a code
python soak_test.py             # T-03, half an hour
python response_time.py         # NZ-5
python clear_dtcs.py            # T-06, this one clears the bank
python freeze_frame.py          # T-09, after re-confirming a DTC
python reconnect_test.py        # T-10
```

`clear_dtcs.py` changes the state of the device, and it has to run before
`freeze_frame.py`, because a freeze frame is captured only on the **first**
confirmation while no valid frame exists. Nothing is written to flash, so a
reset restores the factory scenario.

## Two things worth knowing before reading the numbers

**The adapter, not the device, sets the pace.** Over Bluetooth every request
costs about 200 ms of link latency, and the spread over hundreds of requests is
a few milliseconds. Whatever `throughput.py` prints is a property of the
adapter. The device's own response time is two orders of magnitude smaller and
is measured by `response_time.py`, which tightens the adapter's timeout until
answers start to go missing.

**The screen rounds, the bus does not.** The device shows the internal
floating-point value to a fixed number of decimals, while the bus carries the
value quantised by the conversion formula of the standard. A coolant reading of
110.9 on the screen arrives as 110 on the bus, because the formula's resolution
is 1 °C. `read_sensors.py` prints that resolution next to every row, and a
difference of up to one step is the expected result, not a fault.

## What was measured with these on 22.08.2026.

All eleven test cases of table 14 passed. T-10 was stopped after three cycles
rather than ten, deliberately: J1962 is soldered straight to the board with no
enclosure to take the extraction force.

Highlights, with the raw bytes kept in the project notes rather than here:

- 8840 consecutive requests over 30 minutes, **zero lost responses, zero link
  drops**.
- The device's frame counters agreed with the count kept on the PC **to the
  frame**, once flow-control frames and consecutive frames were accounted for.
- Response time **under 8 ms**, against the 50 ms the standard allows.
- Segmentation moves between services as payload length changes, which is
  visible live by walking one DTC between pending and confirmed.

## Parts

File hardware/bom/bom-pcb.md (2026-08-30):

# Bill of materials, board v0.7

How much of what goes on the final board (**v0.7**, 130 x 115 mm), by group and
by individual value. The counts are taken from
`../kicad/obd2-simulator.kicad_pcb`, not copied from an earlier text.

Alongside this file, the other purchase list is `bom-pcb.csv` in the same
directory, which carries suppliers, order codes and prices. Quantities, values,
tolerances and packages live here.

---

## Total part count for the whole board

| Group | Qty | References |
|---|---|---|
| Resistors | 33 | R7 - R16, R17A, R17B, R19, R21 - R40 |
| Capacitors | 32 | C1, C3 - C7, C10 - C16, C18 - C29, C31 - C37 |
| Inductors | 2 | L2, L3 |
| Diodes | 5 | D1, D2, D3, **D4, D5 (optional)** |
| ICs and modules | 9 | U1, U2, U4 - U7, U9 - U11 |
| Connectors | 5 | J1, J2, J4, J5, J6 |
| Buttons and switches | 6 | SW1 - SW6 |
| Encoder | 1 | ENC1 |
| Crystal | 1 | Y1 |
| Fuse | 1 | F1 |
| **Total to solder** | **95** | |

**The board carries 107 footprints and 95 parts are soldered.** The difference is
12 footprints with no component on them: eight test points TP1 to TP8 and four
mounting holes H1 to H4. Of those 95 parts, D4 and D5 are optional on a first
build, so **93 parts** are enough for a working board.

Passives are 67 of those 95, that is 33 resistors, 32 capacitors and 2
inductors. The other 28 are connectors, semiconductors and electromechanics.

**The display is not counted in the 95.** The 2,4" TFT module with the ILI9341
controller is not on the board but plugs into header J5, and it is listed in
`bom-pcb.csv`.

Reference numbering has gaps (there is no R17 but R17A and R17B, no R18, R20,
J3, U3, U8 and so on), so the part count must not be read off the highest
reference.

### How much of each value to have

#### Resistors, 33 pieces in 11 values

| Value | On board | References | Tolerance | Alternative and note |
|---|---|---|---|---|
| 10 kΩ | 16 | R9 - R15, R22, R28, R29, R32 - R37 | 1 % (5 % passes) | pull-ups for buttons, joystick and encoder, RC on the EN pin, VBUS sense, pull-ups on CS_CAN and CS_FLASH, pull-down on USB_HOST_EN |
| 33 Ω | 3 | R8, R30, R31 | 5 % passes | backlight input (R8), series termination of SCK and MOSI at the module's output pin (R30, R31) |
| 100 Ω | 3 | R38, R39, R40 | 5 % passes | in series in the encoder filter, **the only vertical resistors**, 5,08 mm pitch |
| 6,8 kΩ | 3 | R19, R26, R27 | 1 % | R19 sets the SY6280 current limit to about 1 A, the value matters |
| 51 kΩ | 2 | R16, R24 | **1 %, mandatory** | upper members of the feedback dividers of both converters |
| 120 Ω | 1 | R7 | 1 % | CAN termination, the tolerance defines the bus impedance. 124 Ω or 127 Ω (E96) also pass |
| 1 kΩ | 1 | R21 | 1 % | series VBUS towards the VDD of the CH224K controller. 910 Ω and 1,05 kΩ work equally well |
| 9,31 kΩ | 1 | R25 | **1 %, mandatory, E96** | lower member of the 5 V divider. Substituting 9,1 kΩ gives 5,07 V instead of 4,98 V, which is acceptable |
| 15 kΩ | 1 | R17A | **1 %, mandatory** | upper half of the lower member of the 3,3 V divider, in series with R17B |
| 470 Ω | 1 | R17B | **1 %, mandatory** | lower half, with R17A it gives 15,47 kΩ. 15 kΩ on its own is **not** enough, it gives 3,38 V |
| 24 kΩ | 1 | R23 | **1 %, mandatory** | CH224K CFG1, selects the 12 V PD profile |
| **Total** | **33** | | | |

Where a value is marked "mandatory" the tolerance sets an output voltage or the
selected PD profile, so 5 % is no substitute. Elsewhere 5 % is fine. For every
value it pays to buy two to four spares, because an axial resistor is easily
damaged when its leads are bent, and the price difference is a few cents.

#### Capacitors, 32 pieces in 8 values

| Value | On board | References |
|---|---|---|
| 100 nF | 12 | C10 - C16, C20, C21, C23, C24, C29 |
| 10 µF | 5 | C5, C18, C19, C25, C37 |
| 22 µF low ESR | 4 | C3, C4, C27, C28 |
| 47 nF | 3 | C31, C32, C33 |
| 1 nF | 3 | C34, C35, C36 |
| 1 µF | 2 | C22, C26 |
| 22 pF | 2 | C6, C7 |
| 100 µF | 1 | C1 |
| **Total** | **32** | |

#### Which capacitor type goes with which value

This is the table to buy from. The footprints come from
`../kicad/scripts/build_board.py`, where they are defined.

| Value | References | **Type you must have** | Footprint and pitch | Polarised | Voltage |
|---|---|---|---|---|---|
| 22 pF | C6, C7 | **ceramic disc NP0/C0G** | Ø4,3 x 1,9 mm, RM 5 mm | no | ≥ 50 V |
| 1 nF | C34, C35, C36 | **ceramic disc NP0/C0G**, X7R passes | Ø4,3 x 1,9 mm, RM 5 mm | no | ≥ 50 V |
| 47 nF | C31, C32, C33 | **ceramic disc X7R**, MKT film passes if the body fits | Ø5,0 x 2,5 mm, RM 5 mm | no | ≥ 50 V |
| 100 nF | C10-C16, C20, C21, C23, C24, C29 | **ceramic disc X7R** | Ø5,0 x 2,5 mm, RM 5 mm | no | ≥ 50 V |
| 1 µF | C22, C26 | **ceramic disc or MLCC X7R** | Ø6,0 x 2,5 mm, RM 5 mm | no | ≥ 16 V, 50 V better |
| 10 µF | C5, C18, C19, C25, C37 | **plain aluminium electrolytic, radial** | Ø5,0 mm, up to 7 mm tall, RM 2,0 mm | **yes** | ≥ 25 V, ≥ 10 V is enough for C37 |
| 22 µF | C3, C4, C27, C28 | **low ESR or polymer, radial** | Ø6,3 mm, RM 2,5 mm, also takes RM 2,0 mm | **yes** | C3 and C27 ≥ 25 V, C4 and C28 ≥ 10 V |
| 100 µF | C1 | **aluminium electrolytic, radial** | Ø6,3 mm, RM 2,5 mm | **yes** | ≥ 25 V |

Three rules the table does not show on its own:

- **Polymer parts exist only from 22 µF upwards.** That family starts at a few
  µF, so 47 nF or 1 nF in a polymer type do not exist. Everything up to 1 µF is
  ceramic or film.
- **Never Y5V or Z5U.** Those dielectrics lose up to 80 % of their capacitance
  with voltage and temperature. At 47 nF the encoder filter would be left without
  a time constant, and at 100 nF the supply decoupling would be gone.
- **Ten positions are polarised** (C1, C3, C4, C5, C18, C19, C25, C27, C28,
  C37). The anode, the plus, goes to the supply. All ceramic positions are
  unpolarised and may be soldered either way round.

Why that split: the 22 µF parts are the input and output capacitors of the
converters, where ESR matters and 0,25 to 0,31 A of ripple current flows, so low
ESR or polymer is required. C1 is the 100 µF input reservoir on VBUS, where ESR
is not critical. The 10 µF electrolytics are local reservoirs and a plain type is
enough for them. Everything below 1 µF is ceramic, because it has to work at the
switching frequency of 580 kHz and above, where an electrolytic has no business.

#### Inductors, 2 pieces in 1 value

| Value | On board | References | Note |
|---|---|---|---|
| 4,7 µH | 2 | L2, L3 | Isat ≥ 1,5 A, DCR ≤ 0,1 Ω, **radial**, 5,00 mm pitch, body up to Ø8,5 mm. Table 7-2 of the TPS562201 datasheet gives 4,7 µH as the maximum for both 3,3 V and 5 V |

That makes the passives **67 pieces in 20 different values**. The other 28 parts
are semiconductors, connectors and electromechanics, and each of them goes in one
or two pieces:

| Part | Qty | References |
|---|---|---|
| SMAJ16A, TVS | 2 | D2, D3 |
| USBLC6-2SC6, ESD array (optional) | 2 | D4, D5 |
| TPS562201DDCR, buck converter | 2 | U2, U11 |
| PESD1CAN, ESD for CAN | 1 | D1 |
| CH224K, USB-C PD sink | 1 | U1 |
| MCP2515-I/SO, CAN controller | 1 | U4 |
| SN65HVD230DR, CAN transceiver | 1 | U5 |
| ESP32-S3-WROOM-1-N8R2, module | 1 | U6 |
| S25FL128L, flash | 1 | U7 |
| TS3USB221, USB mux | 1 | U9 |
| SY6280AAC, current switch | 1 | U10 |
| Crystal 8 MHz | 1 | Y1 |
| PTC fuse 500 mA | 1 | F1 |
| Connectors USB-C, USB-A, J1962F, LCD, UART | 5 | J1, J4, J2, J5, J6 |
| Buttons CONFIRM, CLEAR, RETURN, BOOT, RESET | 5 | SW1 - SW5 |
| Joystick SKRHABE010 | 1 | SW6 |
| Encoder EN11-HSB1AQ20 | 1 | ENC1 |

Full data for every value, that is tolerance, voltage and package, is in the
tables above, and suppliers and prices are in `bom-pcb.csv`. Those two documents
are the only purchase lists.

### Optional parts D4 and D5

D4 and D5 are USBLC6-2SC6 ESD arrays on the USB lines and carry the DNP flag, so
they may be skipped on a first build. The board works without them, the USB lines
are simply left without electrostatic discharge protection. If they are fitted,
the note about pin 5 in the soldering section below applies.

---

## What to watch out for when soldering

- **Ten positions are polarised: C1, C3, C4, C5, C18, C19, C25, C27, C28 and
  C37.** The anode (plus) goes to the supply. Those are all the `CP_Radial_*`
  footprints on the board, while ceramics are unpolarised and may be soldered
  either way round. Ø5 mm capacitors with 2,0 mm pitch fit footprints C3, C4,
  C27 and C28, their leads just need easing out to 2,5 mm.
- **D3 is an SMAJ16A, the same part as D2, and pad 1 is the cathode**, which goes
  to OBD_12V, that is towards the connector. A diode fitted the wrong way round
  cuts the tool's supply on pin 16.
- **D4 and D5 are optional.** If they are fitted: **pin 5 goes to +3,3 V, not to
  VBUS.** The reverse standoff voltage of that pin is 5 V, and after the PD
  contract VBUS carries 12 V.
- **R38, R39, R40 stand vertically.** The only three such parts on the board.
- **Pins 4 and 5 of U1 (DP, DM) are deliberately not connected.** Do not "fix"
  that.

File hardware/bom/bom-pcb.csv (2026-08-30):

Block | Component | Description / references | Qty | Package / pitch | Sourcing | Note
Processor | ESP32-S3-WROOM-1-N8R2 | dual-core 240 MHz, 8 MB flash, 2 MB PSRAM (U6) | 1 | SMD module | LCSC (C2913204) | unchanged
CAN | MCP2515-I/SO | CAN 2.0B controller, SPI (U4) | 1 | SOIC-18W | LCSC (C12368) | unchanged; Conrad stocks only the I/ST variant in TSSOP-20, a different footprint
CAN | SN65HVD230DR | CAN transceiver 3,3 V, ISO 11898 (U5) | 1 | SOIC-8 | LCSC (C12084) | unchanged
CAN | Crystal 8 MHz | ABL-8.000MHZ-B2, +-20 ppm (Y1) | 1 | HC-49/U vertical | LCSC (C7060573) | unchanged
OBD | J1962 female | MINITOOLS SEP-A-OBD-D2, 16-pin, now directly on the board (J2) | 1 | THT custom footprint | TME (A-OBD-D) | unchanged
OBD | PESD1CAN | ESD protection for the CAN bus (D1) | 1 | SOT-23 | TME (PESD1CAN.215) | unchanged
UI | Waveshare 18366, TFT 2,4" | ILI9341, 320 x 240, SPI, no touch; connects to J5 | 1 | module | TME (WSH-18366) | unchanged
UI | Tactile button 6 mm | SW1 CONFIRM, SW2 CLEAR, SW3 RETURN, SW4 BOOT, SW5 RESET | 5 | THT 6x6 mm | TME (1825967-1) | unchanged; the footprint has 4 holes 6,5 x 4,5 mm and matches the buttons in stock
UI | SKRHABE010 | Alps 5-way switch, directly on the board (SW6) | 1 | SMD custom footprint | TME (SKRHABE010) | unchanged
UI | Incremental encoder | BI Technologies EN11-HSB1AQ20, 20 pulses and 20 detents per revolution, with a built-in button, directly on the board (ENC1) | 1 | THT, stock footprint RotaryEncoder_Alps_EC11E-Switch_Vertical_H20mm | TME (EN11-HSB1AQ20) | CHANGED 06.08.2026.: replaced potentiometer RV1. Measure the lead pitch with calipers before ordering
Power | USB-C connector | GCT USB4085-GF-A, USB 2.0 + PD (J1) | 1 | SMD | TME (USB4085-GF-A) | unchanged
Power | CH224K | USB-C PD sink, negotiates 12 V (U1) | 1 | ESSOP-10 | LCSC (C970725) | unchanged
Power | TPS562201DDCR | buck converter; U2 gives 3,3 V, U11 gives 5 V | 2 | SOT-23-6 | TME (TPS562201DDCR) | unchanged
Memory | S25FL128LAGMFM010 | 16 MB NOR flash, SPI (U7) - the part actually ordered; an equivalent replacement is the Winbond W25Q128JVSIQ, same package and same pinout | 1 | SOIC-8 208 mil (SOC008) | TME (S25FL128LAGMFM010) | footprint value aligned with the ordered part 05.08.2026.
USB | USB-A connector | female right-angle, socket for a USB stick (J4) | 1 | THT | TME (USB-A-S-RA) | unchanged
USB | TS3USB221DRCR | USB 2.0 analogue mux (U9) | 1 | VSON-10 | LCSC (C324071) | unchanged
USB | SY6280AAC | current-limited 5 V switch (U10) | 1 | SOT-23-5 | LCSC (C55136) | unchanged
Other | Pin header 1x40 | male, cut down for J6 (1x3) | 1 | THT, 2,54 mm | TME (ZL201-40G) | unchanged
Other | Female socket strip 1x40 | cut down for J5 (1x8), the LCD module | 1 | THT, 2,54 mm | TME (ZL262-40SG) | unchanged
NEW THT | Resistor 10 kΩ | pull-ups R9-R14, pull-down R15, VBUS sense R22, SW6 ladder R28/R29 | 10 | metal film 0,6 W 1 %, axial, 10,16 mm pitch | Chipoteka | series "R 0,6 W 1%", package 0207 (6,3 x 2,5 mm)
NEW THT | Resistor 6,8 kΩ | SY6280 ISET (R19), pull-ups for the SW6 axes (R26, R27) | 3 | metal film 0,6 W 1 %, axial, 10,16 mm pitch | Chipoteka | series "R 0,6 W 1%"
NEW THT | Resistor 51 kΩ | upper members of the feedback dividers (R16, R24) | 2 | metal film 0,6 W 1 %, axial, 10,16 mm pitch | Chipoteka | series "R 0,6 W 1%"
NEW THT | Resistor 24 kΩ | CH224K CFG1, selects the 12 V PD profile (R23) | 1 | metal film 0,6 W 1 %, axial, 10,16 mm pitch | Chipoteka | series "R 0,6 W 1%"
NEW THT | Resistor 1 kΩ | series VBUS -> VDD of the CH224K controller (R21) | 1 | metal film 0,6 W 1 %, axial, 10,16 mm pitch | Chipoteka | series "R 0,6 W 1%"
NEW THT | Resistor 120 Ω | CAN termination at the connector (R7) | 1 | metal film 0,6 W 1 %, axial, 10,16 mm pitch | Chipoteka | series "R 0,6 W 1%"
NEW THT | Resistor 33 Ω | series on the display BL input (R8) | 1 | metal film 0,6 W 1 %, axial, 10,16 mm pitch | Chipoteka | series "R 0,6 W 1%"
NEW THT | Resistor 15 kΩ | lower member of the 3,3 V divider, upper half (R17A) | 1 | metal film 0,6 W 1 %, axial, 10,16 mm pitch | Chipoteka | IN SERIES with R17B: 15k + 470R = 15,47 kΩ, output 3,300 V. Substitute for the unobtainable 15,4 kΩ (06.08.2026.). 15 kΩ ALONE is not enough, it gives 3,38 V
NEW THT | Resistor 470 Ω | lower member of the 3,3 V divider, lower half (R17B) | 1 | metal film 0,6 W 1 %, axial, 10,16 mm pitch | Chipoteka | IN SERIES with R17A: 15k + 470R = 15,47 kΩ, output 3,300 V. An alternative 390 Ω gives 3,313 V and passes equally. The 1 % tolerance is mandatory because it sets the output voltage
NEW THT | Resistor 9,31 kΩ | lower member of the 5 V divider (R25) | 1 | metal film 0,6 W 1 %, axial, 10,16 mm pitch | Chipoteka | E96 value. If unavailable, 9,1 kΩ gives 5,07 V instead of 4,98 V, which is acceptable
NEW THT | Capacitor 100 nF | decoupling and bootstrap (C10-C16, C20, C21, C23, C24, C29) | 12 | ceramic disc, RM 5 mm, >= 50 V | Chipoteka | Chipoteka stocks ceramics on a 5 mm pitch and the footprint is matched to that
NEW THT | Capacitor 22 pF | crystal load (C6, C7) | 2 | ceramic disc NP0, RM 5 mm | Chipoteka | same 5 mm pitch
NEW THT | Capacitor 1 µF | VDD of the CH224K controller (C22), RC on the module EN pin (C26) | 2 | ceramic / multilayer, RM 5 mm | Chipoteka | same 5 mm pitch
NEW THT | Capacitor 10 µF | bulk per section (C5, C18, C19, C25) and at the input of switch U10 (C37) | 5 | radial electrolytic, >= 25 V, D5 mm, 2 mm pitch | Chipoteka | polarised, anode to the supply. C37 sits on the 5 V rail so >= 10 V is enough for it, but the same 25 V part passes. C37 added 09.08.2026.: the input of switch U10 had only 100 nF and the nearest electrolytic was 73 mm away
NEW THT | Capacitor 22 µF low ESR | input and output of both converters (C3, C4, C27, C28) | 4 | radial, up to Ø6,3 mm, the footprint is 2,5 mm pitch but also takes 2,0 mm | Chipoteka | THE CRITERION IS IMPEDANCE, NOT CHEMISTRY (10.08.2026.): ESR at 100 kHz <= 0,15 Ω and rated ripple current >= 0,35 A rms. They carry 0,88 A pp on 3,3 V and 1,07 A pp on 5 V, so 0,15 Ω keeps the ripple at 132 and 161 mV. A polymer part meets it (20 to 50 mΩ), as does an electrolytic marked low ESR or low impedance, but NOT a plain electrolytic (about 1 Ω gives 878 mV and pushes the ESP32-S3 and the flash out of specification). If the ESR is worse, add a ceramic 4,7 to 10 µF across the same pads. The low ESR electrolytics already bought, Ø5 mm / 2,0 mm pitch, are used with their leads eased out to 2,5 mm
NEW THT | Capacitor 100 µF | input bulk on VBUS (C1) | 1 | radial electrolytic, 25 V, D6,3 mm, 2,5 mm pitch | Chipoteka | polarised
NEW THT | Inductor 4,7 µH | buck converters (L2, L3) | 2 | radial, 5,00 mm pitch, body up to Ø8,5 mm, up to 12 mm tall | Conrad | CHANGED from 10 µH 09.08.2026. Table 7-2 of the TPS562201 datasheet gives 4,7 µH as the maximum for both 3,3 V and 5 V, and 10 µH was more than double that. With low ESR output capacitors the ripple current at 4,7 µH is 0,25 to 0,31 A rms, which such a part handles easily. Ask for Isat >= 1,5 A and DCR up to 0,1 Ω. On 10.08.2026. the footprint was changed to a radial one (L_Radial_D8.7mm_P5.00mm_Fastron_07HCP), because the part bought is radial too: 4,3 A, 30 mΩ, body Ø8,5 x 11 mm, 5,0 mm lead pitch. An axial footprint draws the body over one hole, while a radial part sits centred between two. Before that the footprint had been enlarged from Ø5,0 to Ø7,5 mm, because it drew a smaller body than the BOM asks for
Power | SMAJ16A-13-F | TVS on the 12 V rail towards pin 16 (D2) and the blocking diode on the same rail (D3) | 2 | SMA (DO-214AC) | TME, LCSC | back to SMD 05.08.2026.; cathode (pad 1) to OBD_12V, polarity corrected. QUANTITY BACK TO 2 (10.08.2026.): D3 is an SMAJ16A again, the request for a Schottky SS34 was withdrawn. Both pieces sit in the same orientation so they cannot be swapped by mistake
Power | 1206L050YR | PTC fuse 0,5 A on the 12 V rail (F1) | 1 | 1206 | TME, LCSC | back to SMD 05.08.2026.
Mechanics | PCB fabrication | 2 layers, 130 x 115 mm, FR4 1,6 mm, min. 5 pieces (v0.7) | 1 | - | JLCPCB, PCBWay, Aisler | size raised from 115 x 100 because of 17 new footprints and the tighter grouping around the ICs
Mechanics | Enclosure | Hammond 1591XXFLBK or 3D printed, to be adapted to the new board size | 1 | - | Conrad, TME | CHECK, an enclosure for 115 x 100 no longer fits (v0.7 is 130 x 115)
NEW | Resistor 33 Ω | series SPI termination at the source (R30 SCK, R31 MOSI) | 2 | metal film 0,6 W 1 %, axial, 10,16 mm pitch | Chipoteka | new 08.08.2026., review section 4.1
NEW | Resistor 10 kΩ | encoder pull-ups (R32 A, R33 B, R34 button) | 3 | metal film 0,6 W 1 %, axial, 10,16 mm pitch | Chipoteka | new 08.08.2026., same value as R9-R15 and can be bought together with them
NEW | Capacitor 47 nF | encoder RC filter (C31 A, C32 B, C33 button) | 3 | ceramic disc, RM 5 mm, >= 50 V | Chipoteka | CHANGED from 10 nF 09.08.2026. With a 10 k pull-up, 10 nF gives 100 µs, while encoder contact bounce lasts on the order of a millisecond, so the node returns to 3,3 V between two bounces and the filter rejects nothing. With 47 nF the constant is 470 µs
NEW | Test point | TP1 3V3, TP2 GND, TP3 CANH, TP4 CANL, TP5 MOSI, TP6 MISO, TP7 SCK, TP8 VBUS | 8 | THT pad 2,0 x 2,0 mm, 1,0 mm hole | - | not a part to buy, just a pad on the board. Solder a wire to it or clip a probe hook on
NEW | Capacitor 1 nF | second capacitor of the encoder lines, right at the module pins (C34, C35, C36) | 3 | ceramic disc NP0/X7R, RM 5 mm | Chipoteka | new 08.08.2026. The C31-C33 filter sits at the encoder, but past it the track still runs 115 to 137 mm across the board. 1 nF, not 10 nF, so the time constant of the line stays around 110 us
NEW | USBLC6-2SC6 | ESD protection for USB-C (D4) and USB-A (D5) | 2 | SOT-23-6 | LCSC, TME | OPTIONAL ON A FIRST BUILD (10.08.2026.): both sit in parallel on their pair, and removing the footprint was measured to leave 0 unconnected items, so the board works with empty footprints and the parts can be added later. They carry the DNP flag in the .kicad_pcb. New 09.08.2026. Both USB connectors had been left without any protection, while the CAN pair has D1. PIN 5 (Vbus) GOES TO +3,3 V, NOT TO VBUS: the standoff of that pin is 5,25 V and VBUS carries 12 V after the PD contract
NEW | Resistor 10 kΩ | pull-up CS_CAN (R35) and CS_FLASH (R36), pull-down USB_HOST_EN (R37) | 3 | metal film 0,6 W 1 %, axial, 10,16 mm pitch | Chipoteka | new 09.08.2026., same value as R9-R15. The CS lines used to float until the firmware took the pin over, and the EN of the SY6280 switch is active high
NEW | Resistor 100 Ω | series in the encoder filter (R38 A, R39 B, R40 button) | 3 | metal film 0,6 W, axial, VERTICAL mounting, 5,08 mm pitch | Chipoteka | new 09.08.2026. The ONLY resistors on the board that stand vertically. Without them the filter capacitor discharges straight through the encoder contact, which is a spike of several amperes through a contact rated for 10 mA

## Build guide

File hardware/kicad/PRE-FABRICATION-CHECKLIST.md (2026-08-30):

# State of revision v0.7

The numbers are measured from the board itself.

| Item | State |
|---|---|
| Outline | 130 x 115 mm, unchanged |
| Footprints | **107** (95 parts to solder + 8 test points + 4 mounting holes), of which **16 SMD** |
| Netlist | **64 nets**, ground included (new: ENC_A_RAW, ENC_B_RAW, ENC_SW_RAW) |
| Routing | **892 segments** (639 top layer, 253 bottom), **73 vias** |
| DRC | **0 errors, 0 warnings, 0 unconnected** |
| Net classes | Default 0,20 mm + **Power 0,40 mm** (SW_3V3, SW_5V, V5_STICK, VBUS_STICK) |
| Track widths | 849 x 0,20 mm, 37 x 0,40 mm, 6 x 0,25 mm (ground bridges) |
| Vias | 72 x 0,60 / 0,30 mm + **1 x 0,80 / 0,40 mm** (net V5_STICK, Power class) |
| Drill | **326 holes**, 17 tools |
| Smallest hole | **0,30 mm** (since 11.08.2026.; before that 0,20 mm on 12 thermal vias under the EPAD of module U6) |
| Smallest hole spacing | **0,400 mm** overall, **0,450 mm** between different nets (it was 0,272 mm before the last repair round) |
| CAN pair | routed by its own script **before** Freerouting: a chain with no stub, **0 vias**, entirely on the top layer. CANH 83,9 mm, CANL 62,2 mm, **0 branch points**, two ends each (transceiver pin and connector pin) |

## BUG IN REVISION v0.7 - the pinout of SW6 (found 21.08.2026.)

**This must be fixed before any future fabrication.** It was found by measuring
on the assembled board, after four directions of the five-way switch did not
work.

The pinout in footprint `SKRHABE010.kicad_mod` **does not match the real part**.
What the netlist calls pad 2, that is net `JOY_SW`, is in reality the **common
contact** of the switch, and the centre contact is on one of the pads the board
ties to ground.

Consequences on the assembled board:

- **All four directions are dead.** Pressing connects the common contact to
  `JOY_X`, `JOY_XB`, `JOY_Y` or `JOY_YB`, but the common contact is `JOY_SW`,
  which R9 holds at 3,3 V through 10k. Two nets that are both already high get
  connected, so the voltage does not move. Measured by the firmware: both axes
  sit at 3159 mV across all 64 samples, without a single bit of deviation.
- **The centre works, but by accident.** Pressing connects the common contact to
  a grounded pad, so `JOY_SW` drops to zero and the firmware reports Select. The
  outcome is the designed one, but the mechanism is entirely different.

The measurement that proves it, a multimeter in continuity mode with the board
unpowered: probes on **pad 2 and pad 1**, moving the stick **left** beeps. No
direction beeps against ground, while `JOY_SW` against ground does.

**Workaround for this board, without a single wire.** The common contact is on
GPIO5, that is on a pin the firmware can drive. `firmware/src/ui/input.cpp`
holds it low, which turns the common contact into the ground the schematic
always assumed, so the directions work exactly as drawn, either through zero or
through the 10k ladder. The centre is read by briefly returning the pin to an
input with a pull-up. The pin **must never be driven high**, because with the
centre pressed that would be a short to ground.

**For the next revision:** pad 2 goes to ground and the centre contact to a
GPIO. Before routing, check the real pinout both against the datasheet and by
**buzzing out a physical part**, because the check in section 2, the one from
18.07.2026., was done from datasheets only and missed this.

---

## Note for the fabricator (the "remarks" field of the order)

The board sits right at the process limit in four places, deliberately. The
problem is not that a fabricator cannot make it, but that an automatic DFM check
will "fix" those items and thereby ruin a part that was drawn that way for a
reason. So they have to be stated up front. The numbers were measured from the
`.kicad_pcb` on 11.08.2026.

Three are mandatory, the rest is useful:

1. **Hole spacing 0,400 mm**, and 0,450 mm between holes of different nets. Those
   0,450 mm are inside the official footprint of the GCT USB4085 USB-C connector
   and must not be changed.
2. **Copper clearance is exactly 0,150 mm everywhere**, without a single
   micrometre of margin. No automatic track spreading may be run.
3. **The mask is drawn with expansion 0**, so the mask bridge between the
   contacts of the USB-C connector is 0,150 mm and the openings may merge. That
   is expected and acceptable, the openings must not be enlarged.

Worth stating alongside: the smallest annular ring is **0,150 mm** (0,60/0,30 mm
vias and 0,70 mm pads over a 0,40 mm hole on J1), the silkscreen has **1688 lines
0,120 mm wide** and one of 0,060 mm on the SW6 footprint, the board has **22
plated slots** and **8 non-plated holes**, impedance is not controlled and no
stencil is ordered.

| Slots (plated) | Non-plated holes |
|---|---|
| 16 x 1,20 x 3,00 mm (J2, OBD-II) | 4 x Ø3,20 mm (H1-H4, M3) |
| 2 x 2,80 x 1,50 mm (ENC1) | 2 x Ø2,60 mm (J2, locating) |
| 2 x 0,60 x 2,10 mm (J1, shield) | 1 x Ø1,20 mm (SW6) |
| 2 x 0,60 x 1,40 mm (J1, shield) | 1 x Ø0,90 mm (SW6) |

### Text to paste

**The remarks field at JLCPCB takes at most 200 characters**, so only what is
critical fits. This text is **196 characters** and covers all three items above:

> Do NOT auto-adjust the design. It is intentionally at process limits:
> hole-to-hole 0.40mm, copper clearance 0.15mm, mask expansion 0 (USB-C mask
> openings may merge). Fabricate exactly as supplied.

Paste it as a single line, without breaks. A shorter version, if the field turns
out tighter still, is 139 characters:

> Do NOT auto-adjust. Intentional: hole-to-hole 0.40mm, clearance 0.15mm, mask
> expansion 0 (USB-C openings may merge). Fabricate as supplied.

**The rest does not go into the field, it waits until they ask.** The annular
ring, the slots, the non-plated holes, the silkscreen and impedance need no
advance note. If the automatic check raises a question, answer in the
correspondence with these details:

> - Minimum annular ring is 0.15 mm (0.60/0.30 mm vias, and 0.70 mm pads over
>   0.40 mm holes on the USB-C connector). Please do not shrink any pad.
> - The 0.45 mm hole pairs are inside the official USB-C connector footprint
>   (GCT USB4085) and cannot be changed.
> - Silkscreen line width is 0.12 mm on most items. If this is below your
>   minimum, please print as is rather than removing items.
> - 22 plated slots: 16 x 1.2 x 3.0 mm (OBD-II connector), 2 x 2.8 x 1.5 mm,
>   2 x 0.6 x 2.1 mm, 2 x 0.6 x 1.4 mm.
> - 8 non-plated holes: 4 x 3.2 mm (M3 mounting), 2 x 2.6 mm, 1 x 1.2 mm,
>   1 x 0.9 mm. These must stay non-plated.
> - No controlled impedance required. No stencil required, the paste layers are
>   deliberately not in the package.

What needs **no** mention at all: the hole diameter (the smallest is 0,30 mm, so
a standard process since 11.08.2026.), the layer count, thickness, copper weight
and surface finish, because all of those are picked in the order form itself.

## To check when ordering and soldering

> **The passive packages are through-hole, not SMD.** The resistors are axial
> DIN0207 on a 10,16 mm pitch (except R38-R40, vertical on 5,08 mm), the ceramics
> are discs on a 5 mm pitch, the electrolytics are radial. The authoritative
> purchase list is `../bom/bom-pcb.csv`. Section 0 below mentions 0603, 0805,
> 1210 and tantalum EIA-3528 - **those are packages from the older, mixed build
> and those parts do not fit these footprints.** SMD remains 16 footprints: U1,
> U2, U4, U5, U6, U7, U9, U10, U11, D1, D2, D3, D4, D5, F1 and **SW6**. Without
> D4 and D5, which carry the DNP flag and may be left unsoldered, that is 14
> parts.

- **The smallest drill is 0,30 mm, so no fine-drill surcharge applies.** Until
  11.08.2026. the board carried 12 holes of 0,20 mm (thermal vias under the EPAD
  of module U6, inherited from the KiCad footprint) and they alone pushed a
  JLCPCB order into the more expensive class. They were widened to 0,30 mm
  without re-routing. **What still has to be checked when ordering is the hole
  spacing**, because the smallest is 0,400 mm while JLCPCB asks for 0,50 mm in
  its standard process. Those are two separate parameters and have to be looked
  at separately in the calculator. See `../gerber/README.md`.
- **The shield of USB-A socket J4 has been on ground since 10.08.2026.** Before
  that it was not, because `build_board.py` assigned ground to pads "5" and "6"
  while the Molex 67643 footprint calls its two mounting tabs **`SH`**. The
  assignment had no effect and the socket housing floated. DRC cannot catch that:
  a pad with no net has nothing to be unconnected from. On J1 the same thing had
  been written correctly. It was fixed both in the script and in the board
  itself, without re-routing, because both pads lie inside the ground pour on the
  bottom layer so the zone fill catches them with thermal spokes.
- **L2, L3 are now 4,7 µH, not 10 µH, and RADIAL.** The 10 µH inductors already
  bought do not fit this board. Ask for Isat ≥ 1,5 A and DCR ≤ 0,1 Ω, a body up
  to Ø8,5 mm, **5,00 mm lead pitch**. On 10.08.2026. the footprint was changed
  from an axial one mounted vertically to
  `L_Radial_D8.7mm_P5.00mm_Fastron_07HCP`, because an axial footprint draws the
  body over one hole while a radial part sits centred between two. Before that
  the footprint was also too small (Ø5,0 and then Ø7,5 mm), so the courtyard did
  not match the actual part.
- **C3, C4, C27, C28 are LOW ESR capacitors**, not plain electrolytics. The
  criterion is impedance, not chemistry: **ESR at 100 kHz ≤ 0,15 Ω** and a
  **rated ripple current ≥ 0,35 A rms**. A polymer part meets that, and so does
  an electrolytic marked "low ESR" or "low impedance". A plain electrolytic does
  **not**, because its 1 Ω gives 878 mV of ripple and pushes the ESP32-S3 and the
  flash out of specification. The footprint is Ø6,3 mm / 2,5 mm pitch, the same
  as C1, but it also takes a part on a 2,0 mm pitch with the leads eased apart.
  **Polarised.**
- **D4 and D5 are OPTIONAL on a first build**, they carry the DNP flag in the
  `.kicad_pcb` and their footprints may stay empty. Measured: removing the
  footprint leaves 0 unconnected items, because they sit in parallel on their
  pair. See `../bom/bom-pcb.md`, the section on optional parts. **No other part
  may be left out** - the router took other nets through the pads of a dozen of
  them.
- **D3 is an SMAJ16A**, the same part as D2, in the forward direction. **Pad 1 is
  the cathode** and goes to OBD_12V. Both pieces of the SMAJ16A already ordered
  are used, D2 and D3, and both sit in the same orientation, so they cannot be
  mixed up. From 09.08. to 10.08.2026. a Schottky SS34 was required here, but
  that requirement was withdrawn - the reasoning is in `../README.md`, section
  "D3 is an SMAJ16A, not a Schottky".
- **D4, D5 (USBLC6-2SC6, SOT-23-6)** - ESD protection for the USB connectors.
  Pin 5 goes to +3,3 V, **not** to VBUS.
- **C31-C33 are 47 nF**, not 10 nF.
- **R38, R39, R40 (100 Ω) stand VERTICALLY**, 5,08 mm pitch. They are the only
  resistors on the board that are not horizontal. One lead is bent downwards.
- **R35, R36, R37 (10 kΩ)** - pull-ups on CS_CAN and CS_FLASH, pull-down on
  USB_HOST_EN. The same value as R9-R15.
- **C37 (10 µF)** - bulk at the input of switch U10.
- **Pins 4 and 5 of U1 (DP/DM) are deliberately unconnected.** If the board is
  ever drawn again, do not "fix" that by connecting them to the USB-C pair - the
  CH224 datasheet, section 5.5, explicitly requires them to be disconnected if
  the A-port protocols are not used. **DEVIATION, established 21.08.2026.:** the
  same sentence in section 5.5 has a second half that the board does not meet.
  Verbatim: "the DP/DM pin on CH224K/CH224D is required to be disconnected from
  the DP/DM on the Type-C connector, **and the DP pin on CH224 is required to be
  shorted to the DM on CH224**." Here both pins are `None` in the netlist, so
  each floats on its own isolated pad. Note that this is not a soldering matter.
  The pins are soldered, each to its own pad, but there is no copper between
  those two pads and the datasheet asks for exactly that connection. The fix is a
  shared net on pins 4 and 5, which are adjacent on a 1 mm pitch, so the trace is
  short. It was not applied to v0.7 because the board was already fabricated and
  soldered, and the PD contract runs purely over the CC lines.

---

# KiCad PCB - status and what to check before fabrication

Project: `obd2-simulator.kicad_pcb` (KiCad 10), revision **v0.7**. It opens in
KiCad, is fully routed and passes DRC **without a single electrical error**.
Even so, this is a **machine-generated design** (the scripts in `scripts/`) and
the checks in section 2 have to be done before ordering fabrication.

> **How to read what follows.** The authoritative board state is in the table at
> the top of this document and in `../README.md`. The sections below explain
> **why a given part was chosen** and **what has to be verified on each part
> against the delivered component**. That still holds unchanged, because those
> parts have not changed. The figures about dimensions, footprint, segment and
> via counts mentioned in those sections come from earlier development steps and
> **are not valid**.

## 0. Alignment with the TME and LCSC orders

The board is aligned with the parts actually ordered:

- **D1 = PESD1CAN** (SOT-23, 1 = CANH, 2 = CANL, 3 = ground) instead of the
  unavailable PRTR5V0U2X. A purpose-made CAN ESD pair, it has no VCC pin so
  **C30 was removed**. *Check the pinout against the Nexperia datasheet before
  fabrication.*
- **J1 = GCT USB4085-GF-A** instead of the LCSC-only HRO connector, with the
  official KiCad footprint. The position (23,15, 74,2) was chosen by a sweep
  (J1_X/J1_Y in `build_board.py`), because at 23,65 the router dropped USBC_DP
  every time. *Check the mechanical fit of the front tab over the board edge on
  the delivered connector.*
- **SW6 = Alps SKRHABE010** (five-way switch) directly on the board instead of an
  analogue joystick and header J3. Custom footprint in
  `footprints/obd2.pretty/` (derived from EasyEDA/LCSC C139794). The axes are
  read as three voltage levels: 6,8 kΩ pull-up (R26/R27), 10 kΩ ladder
  (R28/R29), a direct contact to ground, and the centre click on JOY_SW. *Check
  which direction closes which contact (A/B/C/D) on the real part - swapping the
  pair is a constant in `firmware/src/ui/input.cpp`.* **See the bug at the top of
  this document: this check was done from datasheets only and got the common
  contact wrong.**
- **Passive sizes as ordered**: R19 6,8 kΩ in 0603, R25 9,31 kΩ in 0805, 22 µF in
  1210 (C3/C4/C27/C28), 10 µF as tantalum B EIA-3528 16 V (C5/C18/C19/C25 -
  **polarised**, anode to the supply). *Mind the tantalum polarity when
  soldering.*
- **The USB-A connector is a TME USB-A-S-RA**, while the footprint stayed Molex
  67643. *Compare the hole pitch with the delivered connector before
  fabrication.*
- The module was ordered as an **ESP32-S3-WROOM-1-N8R2** (8 MB flash, 2 MB
  PSRAM), same footprint and pinout.

## 1. How the board reached this state

Addition of 18.07.2026.: a **programming block** was added - service buttons SW4
(BOOT, GPIO0 + pull-up R14) and SW5 (RESET, EN + R13/C26), pull-down R15 on the
USB-SEL line (holding mux U9 on the USB-C side during reset, so the ROM
bootloader is reachable over the USB-Serial-JTAG interface) and net BOOT. The
same day the footprints were corrected to the actual order codes: **F1 to 1206**
(an 0805 PTC rated ≥ 16 V does not exist), **U9 to Texas_DRC0010J** (VSON-10, the
only package the TS3USB221 really comes in), **U7 to SOIC-8 5,3 mm** (208 mil,
the ordered Infineon S25FL128LAGMFM010, the same package as the W25Q128JVSIQ) and
**D2 to D_SMA** (the correction of 16.07. had gone into the .kicad_pcb only and
not into the script, so regeneration had undone it). The board was re-placed and
re-routed with the same scripts. A note on determinism: on the same placement
Freerouting gives an identical result on every run, so a placement either passes
100 % or fails every time. That is why, alongside C15/C16/C19/C24/C25 (v0.5
coordinates, otherwise CC2 fails), U7 (22, 5), F1 (59, 63) and D2 (52.8, 70.4)
are now fixed as well - the candidate positions for F1/D2 were found by a sweep
(environment variables F1_X/F1_Y/D2_X/D2_Y in `build_board.py`).

The pins of module **U6 were verified against the datasheet** of the
ESP32-S3-WROOM-1 v1.8 (table 3-1) and match the firmware configuration
(`firmware/include/pins_custom_s3.h`).

The pins of controller **U1 (CH224K) were verified against the reference
schematic in the official WCH CH224DS1 datasheet**, section 6.1. Note: the pin
table in that same datasheet lists "2, 3, 9 -> CFG1, CFG2, CFG3", from which one
would conclude that CFG1 is pin 2. **That is wrong.** The reference schematic
shows `2 = CFG2`, `3 = CFG3`, `9 = CFG1`. The schematic is what counts.

The voltage selection table on CFG1 was checked on 21.08.2026. in the same
datasheet, section 5.2.1, and reads verbatim: 6,8 kΩ -> 9 V, 24 kΩ -> 12 V,
56 kΩ -> 15 V, **NC -> 20 V**. The same table is repeated next to the reference
schematic in section 6.1. So R23 of 24 kΩ asks for 12 V, and an open CFG1 does
not give 5 V but 20 V. If the board sits at 5 V, the cause is not CFG1. A
diagnostic note: 5 V is the default state of USB-C before any PD contract, so a
board at 5 V means the contract was not made (a source without PD, a source
without a 12 V profile, a cable from an A-port) or that U1 is not running at all.
Per section 7.5, VDD is an internal shunt regulator at 3,24 to 3,36 V that takes
up to 30 mA, so the series R21 of 1 kΩ from VBUS is the correct way to supply it,
and the voltage on pin 1 must be about 3,3 V.

## 2. Pinout checks - RESOLVED 18.07.2026. against the official datasheets

All four previously assumed pinouts were checked against the official datasheets
and three were WRONG and were corrected in the netlist (`build_board.py`) and
re-routed:

| Ref | Component | Finding | Status |
|---|---|---|---|
| U9 | TS3USB221 (USB mux) | **The pinout was wrong** (VCC was on pin 1, SEL on pin 10). Actually (TI SCDS220M, table 4-1): 1/2 = 1D± (port 1 = USB-C), 3/4 = 2D± (port 2 = USB-A), 5 = GND, 6 = OE (low = active), 7 = D-, 8 = D+ (towards the MCU), 9 = S (low = port 1), 10 = VCC, EP = GND. Package: **Texas_DRC0010J** (VSON-10), order the **TS3USB221DRCR**. | Fixed |
| U10 | SY6280AAC (load switch) | **The pinout was mirrored.** Actually (Silergy): 1 = OUT, 2 = GND, 3 = ISET, 4 = EN (active high), 5 = IN. On top of that the input was connected to VBUS (12 V) while the chip takes 5,5 V - it is now fed by the new 5 V converter U11. | Fixed |
| D1 | PRTR5V0U2X (ESD) | **The pinout was wrong** (CANH on the GND pin, 12 V on an I/O pin). Actually (Nexperia, table 2): 1 = GND, 2 = I/O1, 3 = I/O2, 4 = VCC. VCC was then put on +3,3 V (with C30). **Note for v0.7:** on 19.07.2026. D1 was replaced by a PESD1CAN (SOT-23, no VCC pin), so both that pinout and C30 are history - see section 0. | Replaced in v0.7 |
| U2 | TPS562201 (buck converter) | The pinout was **confirmed correct** (TI: 1 = GND, 2 = SW, 3 = VIN, 4 = VFB, 5 = EN, 6 = VBST). | Confirmed |
| U1 | CH224K, **footprint** | The footprint was drawn by hand from the package drawing in the datasheet (ESSOP-10, body 3,9 x 5,0 mm, 1,0 mm pitch, EP 2,3 x 3,2 mm) and does not come from an official library. Compare it against the mechanical drawing. | Medium |
| F1, D2 | 500 mA PTC fuse and TVS SMAJ16A on the 12 V branch towards pin 16 | Check the tool current and the breakdown voltage. **The D2 footprint was corrected on 16.07.2026.**: it had been `D_SMB`, while the SMAJ16A is SMA (DO-214AC) - it is now `D_SMA` (pads 2,5 x 1,8 mm at ±2,0 mm, footprint from the official `Diode_SMD.pretty` library). DRC after the swap was identical to before (the same 3 findings). **The F1 footprint was enlarged to 1206 (applied 18.07.2026.)** - an 0805 PTC with Vmax ≥ 16 V does not exist on the market (the 0805L series goes to 6 - 15 V). The matching part is a Littelfuse 1206L050/24WR (1206, 0,5 A, 24 V). The same regeneration enlarged the U7 footprint from 3,9 mm to **SOIC-8 5,3 x 5,3 mm (208 mil)**, so the ordered flash actually fits. The part fitted is an **Infineon S25FL128LAGMFM010** (package SOC008, SOIC-8 208 mil); the Winbond W25Q128JVSIQ is an equivalent replacement and the firmware accepts both JEDEC ids. | Medium |

**New 5 V stage (U11, 18.07.2026.)**: a second TPS562201 with divider R24/R25 =
51 k / 9,31 k (0,765 V x 6,478 = 4,96 V), inductor L3 (2,2 µH) and capacitors
C27/C28 (22 µF) + C29 (bootstrap). It supplies the SY6280 and the USB stick,
because VBUS carries 12 V after the PD contract. C23 was moved to the 5 V rail as
decoupling at the input of U10.

**Display (18.07.2026.)**: J5 is an **eight-pin** header for the Waveshare 18366
(2,4" ILI9341 without touch, TME symbol WSH-18366), in the order VCC / GND / DIN
/ CLK / CS / DC / RST / BL - with no MISO line (the module is write-only). The
whole Waveshare series of small LCDs shares that order, so it is interchangeable
with one TFT_eSPI flag.

**Note for v0.7:** this sentence used to say that J2, RV1, J3 and J5 were all pin
headers. On this board that no longer holds. **J2 carries a custom footprint of
the real J1962F connector** (MINITOOLS SEP-A-OBD-D2, directly on the board), and
**RV1 and J3 are gone** along with the potentiometer and the analogue joystick,
which were replaced by encoder ENC1 and switch SW6, both also directly on the
board. The only pin header left is **J5 (TFT)**, eight pins, because the display
is mounted on the front panel and wired. J6 is the UART header: a serial monitor
at 115200 baud and a fallback programming channel through an external USB-serial
converter. The primary programming path is USB-C (USB-Serial-JTAG in the
ESP32-S3 ROM), with buttons BOOT (SW4) and RESET (SW5) for entering download mode
by hand.

## 3. The compromise around the antenna keepout

The ESP32-S3-WROOM-1 footprint carries Espressif's RF keepout (~21 x 48 mm). The
decision was made while the board was 100 x 80 mm: with the user interface along
the right edge, that zone sat exactly between the microcontroller and the UI
column, so no display or interface signal could get through. The zone from the
**project documentation (3-5 mm)** was applied instead and Espressif's was
removed. The outline is 130 x 115 mm today and there is more room, but the zone
was not restored, because restoring it would require re-routing the entire right
half of the board. The firmware does not use Wi-Fi or BLE. **If the radio is ever
needed**, the module has to move to the board edge so that the antenna sticks out
beyond it.

## 4. Procedure before ordering

1. Check the pinouts and the footprint from the table in section 2 and correct
   the connections.
2. Run DRC (Inspect -> Design Rules Checker) - it must stay free of electrical
   errors.
3. Check the CAN pair (CANH/CANL): unbroken, no vias, no branches, termination R7
   at the connector.
4. Re-export the Gerber and drill files (`../gerber/`) and send them for
   fabrication.

## 5. History of the power section

The power section used to be designed around the **IP2368**, described in the
documentation as "a USB-C PD controller with an integrated buck converter".
**That was a component selection error.** According to the official datasheet
(Injoinic v1.40), the IP2368 is a *lithium battery charger* (2-5 cells in series,
QFN-48 7 x 7 mm), it needs a battery pack and it has no feedback divider of the
kind the documentation described. Because of that the PD stage was never actually
drawn, and bridge **R20 (0 Ω)** quietly fed the buck straight from the 5 V VBUS.

The IP2368 was therefore replaced by the **CH224K**, which is a real PD sink: it
negotiates 12 V with the charger and the charger puts it on VBUS. That dropped L1
(4,7 µH), C2 (100 µF), R3 (PROG), R4 (EN), R5/R6 (feedback divider), bridge R20
and R1/R2 (5,1 kΩ on the CC lines, since the CH224K has Rd built in) out of the
design. R21 (1 kΩ), R22 (10 kΩ), R23 (24 kΩ, selecting the 12 V profile) and C22
(1 µF) were added.

## 6. How the project is generated

The scripts in `scripts/` (KiCad Python API + Freerouting):

- `build_board.py` - outline, footprints, netlist, placement by zones, zones,
  design rules. Decoupling capacitors are placed **before** the rest of the
  components in a zone, so they really do end up next to their supply pin
  (2 - 6 mm) rather than 8-12 mm away as in earlier drafts,
- `place.py` - placement without overlaps,
- `dsn_export.py` / `ses_import.py` - Specctra export/import, thermal vias, GND
  bridges, zone filling,
- `generate_figures.py`, `generate_drawing.py`, `generate_pcb_html.py` -
  schematics, the dimensioned drawing and the interactive view, all from the
  actual board.

The custom CH224K footprint is in `footprints/obd2.pretty/`.

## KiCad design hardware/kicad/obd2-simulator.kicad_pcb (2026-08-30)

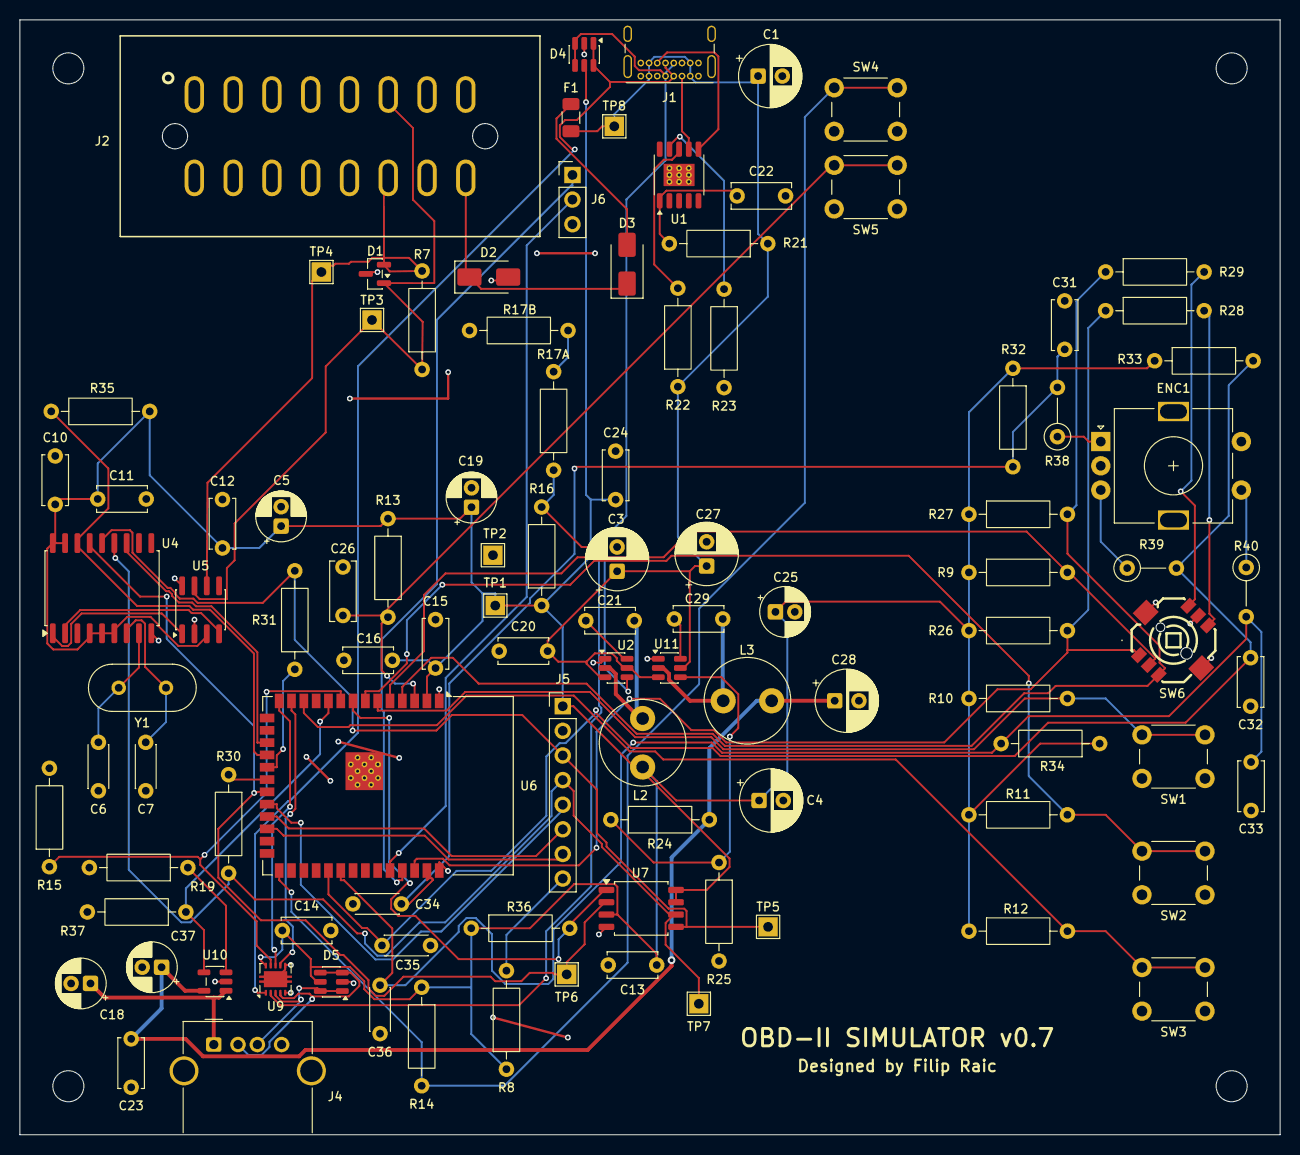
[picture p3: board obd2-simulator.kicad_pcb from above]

Board: 2 copper layers, 130.0 x 115.0 mm, 107 parts (0 on the bottom side), 64 nets.

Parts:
C1: 100uF/25V; CP_Radial_D6.3mm_P2.50mm
C3, C4, C27, C28: 22uF LowESR; CP_Radial_D6.3mm_P2.50mm
C5, C18, C19, C25, C37: 10uF; CP_Radial_D5.0mm_P2.00mm
C6, C7: 22pF; C_Disc_D4.3mm_W1.9mm_P5.00mm
C10, C11, C12, C13, C14, C15, C16, C20, C21, C23, C24, C29: 100nF; C_Disc_D5.0mm_W2.5mm_P5.00mm
C22, C26: 1uF; C_Disc_D6.0mm_W2.5mm_P5.00mm
C31, C32, C33: 47nF; C_Disc_D5.0mm_W2.5mm_P5.00mm
C34, C35, C36: 1nF; C_Disc_D4.3mm_W1.9mm_P5.00mm
D1: PESD1CAN; SOT-23
D2, D3: SMAJ16A; D_SMA
D4, D5: USBLC6-2SC6; SOT-23-6
ENC1: EN11-HSB1AQ20; RotaryEncoder_Alps_EC11E-Switch_Vertical_H20mm
F1: PTC 500mA; Fuse_1206_3216Metric
H1, H2, H3, H4: M3; MountingHole_3.2mm_M3
J1: USB-C; USB_C_Receptacle_GCT_USB4085
J2: J1962F OBD-II; SEP-A-OBD-D2
J4: USB-A; USB_A_Molex_67643_Horizontal
J5: LCD 18366; PinHeader_1x08_P2.54mm_Vertical
J6: UART; PinHeader_1x03_P2.54mm_Vertical
L2, L3: 4u7H; L_Radial_D8.7mm_P5.00mm_Fastron_07HCP
R7: 120R; R_Axial_DIN0207_L6.3mm_D2.5mm_P10.16mm_Horizontal
R8, R30, R31: 33R; R_Axial_DIN0207_L6.3mm_D2.5mm_P10.16mm_Horizontal
R9, R10, R11, R12, R13, R14, R15, R22, R28, R29, R32, R33, R34, R35, R36, R37: 10k; R_Axial_DIN0207_L6.3mm_D2.5mm_P10.16mm_Horizontal
R16, R24: 51k; R_Axial_DIN0207_L6.3mm_D2.5mm_P10.16mm_Horizontal
R17A: 15k; R_Axial_DIN0207_L6.3mm_D2.5mm_P10.16mm_Horizontal
R17B: 470R; R_Axial_DIN0207_L6.3mm_D2.5mm_P10.16mm_Horizontal
R19, R26, R27: 6k8; R_Axial_DIN0207_L6.3mm_D2.5mm_P10.16mm_Horizontal
R21: 1k; R_Axial_DIN0207_L6.3mm_D2.5mm_P10.16mm_Horizontal
R23: 24k; R_Axial_DIN0207_L6.3mm_D2.5mm_P10.16mm_Horizontal
R25: 9k31; R_Axial_DIN0207_L6.3mm_D2.5mm_P10.16mm_Horizontal
R38, R39, R40: 100R; R_Axial_DIN0207_L6.3mm_D2.5mm_P5.08mm_Vertical
SW1: CONFIRM; SW_PUSH_6mm
SW2: CLEAR; SW_PUSH_6mm
SW3: RETURN; SW_PUSH_6mm
SW4: BOOT; SW_PUSH_6mm
SW5: RESET; SW_PUSH_6mm
SW6: SKRHABE010
TP1: 3V3; TestPoint_THTPad_2.0x2.0mm_Drill1.0mm
TP2: GND; TestPoint_THTPad_2.0x2.0mm_Drill1.0mm
TP3: CANH; TestPoint_THTPad_2.0x2.0mm_Drill1.0mm
TP4: CANL; TestPoint_THTPad_2.0x2.0mm_Drill1.0mm
TP5: MOSI; TestPoint_THTPad_2.0x2.0mm_Drill1.0mm
TP6: MISO; TestPoint_THTPad_2.0x2.0mm_Drill1.0mm
TP7: SCK; TestPoint_THTPad_2.0x2.0mm_Drill1.0mm
TP8: VBUS; TestPoint_THTPad_2.0x2.0mm_Drill1.0mm
U1: CH224K; CH224K_ESSOP-10-1EP_3.9x5.0mm_P1mm_EP2.3x3.2mm
U2, U11: TPS562201DDCR; SOT-23-6
U4: MCP2515-I/SO; SOIC-18W_7.5x11.6mm_P1.27mm
U5: SN65HVD230DR; SOIC-8_3.9x4.9mm_P1.27mm
U6: ESP32-S3-WROOM-1
U7: S25FL128LAGMFM010; SOIC-8_5.3x5.3mm_P1.27mm
U9: TS3USB221; Texas_DRC0010J
U10: SY6280AAC; SOT-23-5
Y1: 8MHz; Crystal_HC49-U_Vertical

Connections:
+3V3: C4.1, C5.1, C10.1, C11.1, C12.1, C13.1, C14.1, C15.1, C16.1, C19.1, C24.1, C25.1, D4.5, D5.5, J5.1, L2.2, R8.1, R9.1, R10.1, R11.1, R12.1, R13.1, R14.1, R16.1, R26.1, R27.1, R32.1, R33.1, R34.1, R35.1, R36.1, TP1.1, U4.4, U4.5, U4.6, U4.17, U4.18, U5.3, U6.2, U7.3, U7.7, U7.8, U9.10
BOOT: R14.2, SW4.1, U6.27
BST_3V3: C21.2, U2.6
BST_5V: C29.2, U11.6
BTN_CLEAR: R11.2, SW2.1, U6.7
BTN_CONFIRM: R10.2, SW1.1, U6.6
BTN_RETURN: R12.2, SW3.1, U6.12
CANH: D1.1, J2.6, R7.1, TP3.1, U5.7
CANL: D1.2, J2.14, R7.2, TP4.1, U5.6
CAN_RX: U4.2, U5.4
CAN_TX: U4.1, U5.1
CC1: J1.A5, U1.7
CC2: J1.B5, U1.6
CS_CAN: R35.2, U4.16, U6.18
CS_FLASH: R36.2, U6.8, U7.1
CS_TFT: J5.5, U6.22
ENC_A: C31.1, C34.1, R32.2, R38.2, U6.39
ENC_A_RAW: ENC1.A, R38.1
ENC_B: C32.1, C35.1, R33.2, R39.2, U6.31
ENC_B_RAW: ENC1.B, R39.1
ENC_SW: C33.1, C36.1, R34.2, R40.2, U6.32
ENC_SW_RAW: ENC1.S1, R40.1
FB_3V3: R16.2, R17A.1, U2.4
FB_5V: R24.2, R25.1, U11.4
FB_MID: R17A.2, R17B.1
FUSED_12V: D3.2, F1.2
GND: C1.2, C3.2, C4.2, C5.2, C6.2, C7.2, C10.2, C11.2, C12.2, C13.2, C14.2, C15.2, C16.2, C18.2, C19.2, C20.2, C22.2, C23.2, C24.2, C25.2, C26.2, C27.2, C28.2, C31.2, C32.2, C33.2, C34.2, C35.2, C36.2, C37.2, D1.3, D2.2, D4.2, D5.2, ENC1.C, ENC1.MP, ENC1.S2, J1.A1, J1.A12, J1.B1, J1.B12, J1.SH, J2.4, J2.5, J4.4, J4.SH, J5.2, J6.3, R15.2, R17B.2, R19.2, R23.2, R25.2, R37.2, SW1.2, SW2.2, SW3.2, SW4.2, SW5.2, SW6.5, SW6.7, SW6.8, TP2.1, U1.0, U2.1, U4.9, U5.2, U5.8, U6.1, U6.40, U6.41, U7.4, U9.5, U9.6, U9.11, U10.2, U11.1
INT_CAN: U4.12, U6.17
ISET: R19.1, U10.3
JOY_SW: R9.2, SW6.2, U6.5
JOY_X: R26.2, R28.1, SW6.1, U6.38
JOY_XB: R28.2, SW6.6
JOY_Y: R27.2, R29.1, SW6.3, U6.4
JOY_YB: R29.2, SW6.4
MCU_EN: C26.1, R13.2, SW5.1, U6.3
MISO: TP6.1, U4.15, U6.21, U7.2
MOSI: J5.3, R31.2, TP5.1, U4.14, U7.5
MOSI_MCU: R31.1, U6.19
OBD_12V: D2.1, D3.1, J2.16
PD_CFG1: R23.1, U1.9
PD_SENSE: R22.2, U1.8
PD_VDD: C22.1, R21.2, U1.1
RXD0: J6.2, U6.36
SCK: J5.4, R30.2, TP7.1, U4.13, U7.6
SCK_MCU: R30.1, U6.20
SW_3V3: C21.1, L2.1, U2.2
SW_5V: C29.1, L3.1, U11.2
TFT_DC: J5.6, U6.23
TFT_LED: J5.8, R8.2
TFT_RST: J5.7, U6.24
TXD0: J6.1, U6.37
USBA_DM: D5.3, D5.4, J4.2, U9.4
USBA_DP: D5.1, D5.6, J4.3, U9.3
USBC_DM: D4.3, D4.4, J1.A7, J1.B7, U9.2
USBC_DP: D4.1, D4.6, J1.A6, J1.B6, U9.1
USB_DM: U6.13, U9.7
USB_DP: U6.14, U9.8
USB_HOST_EN: R37.1, U6.10, U10.4
USB_SEL: R15.1, U6.9, U9.9
V5_STICK: C23.1, C28.1, C37.1, L3.2, R24.1, U10.5
VBUS: C1.1, C3.1, C20.1, C27.1, F1.1, J1.A4, J1.A9, J1.B4, J1.B9, R21.1, R22.1, TP8.1, U2.3, U2.5, U11.3, U11.5
VBUS_STICK: C18.1, J4.1, U10.1
XTAL1: C6.1, U4.8, Y1.1
XTAL2: C7.1, U4.7, Y1.2

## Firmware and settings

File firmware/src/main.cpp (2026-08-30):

// main.cpp
// OBD-II simulator firmware entry point.
// setup() initialises the shared SPI bus and storage, then starts the two
// FreeRTOS tasks: the high-priority CAN task (protocol core + MCP2515) and
// the low-priority UI task (ILI9341 + physical controls). On the dedicated
// ESP32-S3 board (v0.5) an NVS flag can select the PC-link boot mode
// instead, where the device exposes its scenario storage over USB-C as an
// MSC disk. The Arduino loop stays idle - all work happens in the tasks.
#include <Arduino.h>
#include "hal/spi_bus.h"
#if defined(BRINGUP_DIAG)
#include "hal/bitbang_probe.h"
#endif
#if defined(BRINGUP_DIAG)
#include "hal/crash_report.h"
#else
#define crash_stage(n) ((void)0)
#endif
#include "storage/storage.h"
#if defined(BRINGUP_DIAG)
#include "storage/flash_fs.h"
#endif
#include "storage/usb_msc_device.h"
#include "can/can_task.h"
#include "ui/ui_task.h"
#include "board_config.h"

void setup() {
    Serial.begin(115200);
    Serial.println("\nOBD-II Simulator");

#if defined(BRINGUP_DIAG)
    // Why did the PREVIOUS boot end? Printed before anything else can crash
    // again. This is the answer to the panic text that never arrives over
    // USB-C - see hal/crash_report.h.
    crash_report_print();
#endif
    crash_stage(10);

#if defined(BRINGUP_DIAG)
    // Before the SPI peripheral claims the pins - see hal/bitbang_probe.h.
    hal::bitbang_probe();
#endif

    hal::spi_bus_init();

#if defined(BOARD_HAS_USB)
    if (usb_msc::boot_requested())
        usb_msc::run();                 // never returns (reboots)
    usb_msc::pins_init_normal_mode();   // mux -> USB-C, stick power off
#endif

    storage::init();
    crash_stage(20);

    // Display first, while the SPI bus still has no other user.
    ui_display_init();
#if defined(BRINGUP_NO_CAN)
    // The other half of the bisection, see BRINGUP_NO_UI below. With the CAN
    // task left out, a UI that then reaches its main loop puts the fault in
    // the interaction between the two tasks over the shared SPI bus, and a UI
    // that still dies inside s_tft.init() puts it in the display path alone.
    Serial.println("[boot] CAN task DISABLED (BRINGUP_NO_CAN)");
    Serial.flush();
#else
    can_task_start();
    Serial.println("[boot] can_task_start returned");
    Serial.flush();
#endif
#if defined(BRINGUP_NO_UI)
    // Bring-up bisection (20.08.2026.): the board panics and reboots once the
    // tasks are up, and the panic text is lost - USB-Serial-JTAG delivers only
    // the tail of the last line, "ELF file SHA256:", so the Guru Meditation
    // line and the backtrace never arrive. With the UI task left out, a CAN
    // task that then loops quietly through it0/it1/it2 puts the fault in the
    // UI path, and one that still dies puts it in the CAN path.
    Serial.println("[boot] UI task DISABLED (BRINGUP_NO_UI)");
    Serial.flush();
#else
    ui_task_start();
    Serial.println("[boot] ui_task_start returned");
    Serial.flush();
#endif
}

#if defined(BRINGUP_DIAG)
// Repeated SPI probe, added 22.08.2026.
//
// Everything about this fault has to be read off a boot log that arrives over
// USB-C, and RESET takes the USB device down with it, so the first seconds are
// lost every single time. The two lines that decide where to look next are
// printed at boot and only at boot: whether the flash answers its JEDEC probe
// and whether the MCP2515 answers its CNF1 readback. Printing them again every
// few seconds costs nothing and cannot be missed by a capture that starts late.
//
// How to read the result:
//   jedec 01 60 18   the flash answers, so SCK, MOSI and MISO all reach the
//                    bottom of the chain and the bus is healthy. A mute
//                    MCP2515 is then its own problem - crystal Y1, CS_CAN or
//                    the chip's own supply.
//   jedec ff ff ff   nothing drives MISO. Either no slave answers at all
//                    (SCK or MOSI broken past the display branch, or both
//                    chips unpowered) or MISO is stuck high.
//   jedec 00 00 00   MISO is held low, which is a short to ground rather than
//                    a silent slave.
// miso_idle is the pad level with every chip select high, and it separates a
// floating line from a stuck one.
static void bringup_spi_probe() {
    hal::SpiLock lock;
    SPI.beginTransaction(SPISettings(1000000, MSBFIRST, SPI_MODE0));

    uint8_t id[3] = {0, 0, 0};
    digitalWrite(PIN_CS_FLASH, LOW);
    SPI.transfer(0x9F);                       // JEDEC ID
    for (uint8_t& b : id) b = SPI.transfer(0x00);
    digitalWrite(PIN_CS_FLASH, HIGH);

    digitalWrite(PIN_CS_CAN, LOW);            // MCP2515 WRITE CNF1 = 0x55
    SPI.transfer(0x02);
    SPI.transfer(0x2A);
    SPI.transfer(0x55);
    digitalWrite(PIN_CS_CAN, HIGH);
    delayMicroseconds(10);
    digitalWrite(PIN_CS_CAN, LOW);            // MCP2515 READ CNF1
    SPI.transfer(0x03);
    SPI.transfer(0x2A);
    uint8_t cnf1 = SPI.transfer(0x00);
    digitalWrite(PIN_CS_CAN, HIGH);

    SPI.endTransaction();

    Serial.printf("[probe] jedec %02x %02x %02x   cnf1 %02x   miso_idle %d\n",
                  id[0], id[1], id[2], cnf1, digitalRead(PIN_SPI_MISO));
    // Repeated with it, because the bit-bang probe runs once at boot and the
    // first seconds of the log are what USB-C keeps losing.
    Serial.printf("[bitbang] %s\n", hal::bitbang_result());
    Serial.printf("[fs] %s\n", flash_fs::mount_summary());
    Serial.flush();
}
#endif

void loop() {
#if defined(BRINGUP_DIAG)
    bringup_spi_probe();
    vTaskDelay(pdMS_TO_TICKS(3000));
#else
    vTaskDelay(pdMS_TO_TICKS(1000));
#endif
}

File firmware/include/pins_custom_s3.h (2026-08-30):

// pins_custom_s3.h
// GPIO assignment for the ESP32-S3-WROOM-1 module: the single hardware-first target,
// used on the breadboard adapter during development and on the dedicated PCB.
// This is the authoritative map:
// analog inputs on ADC1 (GPIO1-10), strapping pins (3, 45, 46) and the
// flash/octal-PSRAM range (GPIO26-37) avoided. GPIO0 keeps its standard
// strapping role only: the BOOT button (SW4), never a firmware signal.
#pragma once

// Shared SPI bus (FSPI)
constexpr int PIN_SPI_SCK  = 12;
constexpr int PIN_SPI_MISO = 13;
constexpr int PIN_SPI_MOSI = 11;

// CAN controller (MCP2515)
constexpr int PIN_CS_CAN   = 10;
constexpr int PIN_INT_CAN  = 9;

// Display (ILI9341) - also configured for TFT_eSPI via build flags
constexpr int PIN_CS_TFT   = 14;
constexpr int PIN_DC_TFT   = 21;
constexpr int PIN_RST_TFT  = 47;

// Memory
constexpr int PIN_CS_FLASH = 15;  // W25Q128 (primary storage, FAT filesystem)

// USB (v0.5): one OTG controller on fixed pins, switched between the USB-C
// connector (MSC device, PC link) and the USB-A receptacle (stick host) by
// the TS3USB221 analog mux, and stick VBUS goes through the SY6280 load switch.
// A hardware-first pull-down (R15) holds the mux select LOW while no firmware
// drives it, so at reset the OTG pins face USB-C and the ROM bootloader's
// USB-Serial-JTAG is reachable for flashing (see "Programming" below).
constexpr int PIN_USB_DN      = 19;  // fixed OTG D- (informational)
constexpr int PIN_USB_DP      = 20;  // fixed OTG D+ (informational)
// Mux select: LOW = USB-C, HIGH = USB-A. The firmware KEEPS IT LOW in normal
// operation and raises it only for the duration of a stick session, so the
// ROM's USB-Serial-JTAG stays reachable from a PC and uploads need no button
// presses (see pins_init_normal_mode in src/storage/usb_msc_device.cpp).
constexpr int PIN_USB_SEL     = 16;
// 5 V load-switch enable for USB-A, active high, with a 10 k pull-down (R37)
// so the stick supply stays off until the firmware asks for it.
constexpr int PIN_USB_HOST_EN = 17;

// Programming (informational - none of these are driven by the firmware).
// Upload runs over USB-C via the ROM USB-Serial-JTAG on the fixed OTG pins:
// `pio run -e custom-board -t upload`, with no button presses. The running
// application never calls USB.begin(), so the USB PHY stays routed to the
// USB-Serial-JTAG controller instead of the OTG one, and the mux stays on
// the USB-C side, so esptool sees a port and resets the chip itself.
//
// The manual path - hold BOOT (SW4, GPIO0 low), tap RESET (SW5, EN), release
// BOOT, then upload - is needed only when that port is genuinely gone: in the
// MSC device role (USB.begin() has taken the OTG controller) or when the
// firmware hangs before pins_init_normal_mode() runs.
//
// The serial monitor stays on UART0 (ARDUINO_USB_CDC_ON_BOOT=0) and is
// exposed on header J6 for an external USB-UART adapter. That header carries
// only TX, RX and GND, so the UART path always needs the two buttons.
constexpr int PIN_BOOT_BTN    = 0;   // SW4 to GND, 10 k pull-up (R14)
constexpr int PIN_UART0_TX    = 43;  // J6 pin 1, 115200 baud monitor
constexpr int PIN_UART0_RX    = 44;  // J6 pin 2
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

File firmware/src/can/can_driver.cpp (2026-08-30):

// can_driver.cpp
#include "can_driver.h"
#include "can_handler.h"   // OBD_FUNCTIONAL_ID / OBD_PHYSICAL_ID
#include "hal/spi_bus.h"
#include <Arduino.h>
#include <SPI.h>

static const SPISettings kSpiSettings(10000000, MSBFIRST, SPI_MODE0);

constexpr uint8_t CanDriver::REG_RXF_SIDH[6];

// ── Low-level SPI access (always under the shared-bus mutex) ────────────────

uint8_t CanDriver::readRegister(uint8_t reg) {
    hal::SpiLock lock;
    SPI.beginTransaction(kSpiSettings);
    digitalWrite(cs_pin_, LOW);
    SPI.transfer(CMD_READ);
    SPI.transfer(reg);
    uint8_t v = SPI.transfer(0x00);
    digitalWrite(cs_pin_, HIGH);
    SPI.endTransaction();
    return v;
}

void CanDriver::readRegisters(uint8_t reg, uint8_t* data, uint8_t n) {
    hal::SpiLock lock;
    SPI.beginTransaction(kSpiSettings);
    digitalWrite(cs_pin_, LOW);
    SPI.transfer(CMD_READ);
    SPI.transfer(reg);
    for (uint8_t i = 0; i < n; ++i) data[i] = SPI.transfer(0x00);
    digitalWrite(cs_pin_, HIGH);
    SPI.endTransaction();
}

void CanDriver::writeRegister(uint8_t reg, uint8_t value) {
    writeRegisters(reg, &value, 1);
}

void CanDriver::writeRegisters(uint8_t reg, const uint8_t* data, uint8_t n) {
    hal::SpiLock lock;
    SPI.beginTransaction(kSpiSettings);
    digitalWrite(cs_pin_, LOW);
    SPI.transfer(CMD_WRITE);
    SPI.transfer(reg);
    for (uint8_t i = 0; i < n; ++i) SPI.transfer(data[i]);
    digitalWrite(cs_pin_, HIGH);
    SPI.endTransaction();
}

void CanDriver::bitModify(uint8_t reg, uint8_t mask, uint8_t value) {
    hal::SpiLock lock;
    SPI.beginTransaction(kSpiSettings);
    digitalWrite(cs_pin_, LOW);
    SPI.transfer(CMD_BIT_MODIFY);
    SPI.transfer(reg);
    SPI.transfer(mask);
    SPI.transfer(value);
    digitalWrite(cs_pin_, HIGH);
    SPI.endTransaction();
}

void CanDriver::reset() {
    hal::SpiLock lock;
    SPI.beginTransaction(kSpiSettings);
    digitalWrite(cs_pin_, LOW);
    SPI.transfer(CMD_RESET);
    digitalWrite(cs_pin_, HIGH);
    SPI.endTransaction();
    delay(10);  // oscillator start-up; controller wakes in configuration mode
}

// ── Configuration ────────────────────────────────────────────────────────────

void CanDriver::setStandardId(uint8_t sidh_reg, uint32_t id) {
    uint8_t regs[4] = {
        static_cast<uint8_t>(id >> 3),           // SIDH
        static_cast<uint8_t>((id & 0x07) << 5),  // SIDL (standard frame)
        0x00, 0x00                               // EID8, EID0
    };
    writeRegisters(sidh_reg, regs, 4);
}

bool CanDriver::setNormalMode() {
    bitModify(REG_CANCTRL, 0xE0, 0x00);
    for (int i = 0; i < 10; ++i) {
        if ((readRegister(REG_CANSTAT) & 0xE0) == 0x00) return true;
        delay(1);
    }
    return false;
}

bool CanDriver::begin(int cs_pin) {
    cs_pin_ = cs_pin;
    pinMode(cs_pin_, OUTPUT);
    digitalWrite(cs_pin_, HIGH);

    reset();

    // Probe: CNF1 must read back, otherwise no controller is present.
    writeRegister(REG_CNF1, 0x55);
    if (readRegister(REG_CNF1) != 0x55) return false;

    // Bit timing for 500 kbit/s with the 8 MHz crystal.
    //
    // CNF1 = 0x00: SJW = 1 TQ, BRP = 0, so TQ = 2 x (BRP+1) / 8 MHz = 250 ns.
    // A 500 kbit/s bit is 2 us, which is 8 TQ, and 8 TQ is the only choice
    // here: BRP = 1 would give 500 ns per TQ and just 4 TQ per bit, below the
    // 8 TQ minimum.
    //
    // SAMPLE POINT MOVED FROM 62,5 % TO 75 % (09.08.2026.).
    //   was: Sync 1 + Prop 1 + PS1 3 + PS2 3 -> (1+1+3)/8 = 62,5 %
    //   now: Sync 1 + Prop 2 + PS1 3 + PS2 2 -> (1+2+3)/8 = 75 %
    // Both are exactly 500 kbit/s; only where the bit is read changes. CAN
    // practice puts the sample point at 75 to 87,5 %, and diagnostic tools are
    // built around that, so 62,5 % left the smallest margin exactly against the
    // devices this board exists to talk to. 87,5 % is not reachable with 8 TQ,
    // because it would need PS2 = 1 TQ and the MCP2515 requires PS2 >= 2 TQ.
    //
    // CNF2 = 0x91: BTLMODE 1 (PS2 from CNF3), SAM 0 (sample once),
    //              PHSEG1 = 010b -> PS1 = 3 TQ, PRSEG = 001b -> Prop = 2 TQ.
    // CNF3 = 0x01: PHSEG2 = 001b -> PS2 = 2 TQ.
    // Datasheet constraints hold: PS2 >= 2 TQ, PS2 >= SJW (1 TQ), and
    // Prop + PS1 = 5 TQ >= PS2.
    writeRegister(REG_CNF1, 0x00);
    writeRegister(REG_CNF2, 0x91);
    writeRegister(REG_CNF3, 0x01);

    // Accept only the OBD request identifiers 0x7DF and 0x7E0 on both
    // receive buffers (RXB1 catches rollover), everything else is ignored.
    setStandardId(REG_RXM0SIDH, 0x7FF);
    setStandardId(REG_RXM1SIDH, 0x7FF);
    setStandardId(REG_RXF_SIDH[0], OBD_FUNCTIONAL_ID);  // RXB0
    setStandardId(REG_RXF_SIDH[1], OBD_PHYSICAL_ID);
    setStandardId(REG_RXF_SIDH[2], OBD_FUNCTIONAL_ID);  // RXB1
    setStandardId(REG_RXF_SIDH[3], OBD_PHYSICAL_ID);
    setStandardId(REG_RXF_SIDH[4], OBD_FUNCTIONAL_ID);
    setStandardId(REG_RXF_SIDH[5], OBD_PHYSICAL_ID);
    writeRegister(REG_RXB0CTRL, 0x04);  // BUKT: roll over to RXB1 when full
    writeRegister(REG_RXB1CTRL, 0x00);

    // Interrupt on either receive buffer, then enter normal mode.
    writeRegister(REG_CANINTE, IRQ_RX0IF | IRQ_RX1IF);
    return setNormalMode();
}

// ── Receive / transmit ───────────────────────────────────────────────────────

bool CanDriver::readRxBuffer(uint8_t sidh_reg, CanFrame& out) {
    uint8_t raw[13];  // SIDH SIDL EID8 EID0 DLC D0..D7
    readRegisters(sidh_reg, raw, 13);
    out.id  = (static_cast<uint32_t>(raw[0]) << 3) | (raw[1] >> 5);
    out.dlc = raw[4] & 0x0F;
    if (out.dlc > 8) out.dlc = 8;
    for (uint8_t i = 0; i < 8; ++i) out.data[i] = raw[5 + i];
    return true;
}

bool CanDriver::receive(CanFrame& out) {
    uint8_t intf = readRegister(REG_CANINTF);
    if (intf & IRQ_RX0IF) {
        readRxBuffer(REG_RXB0SIDH, out);
        bitModify(REG_CANINTF, IRQ_RX0IF, 0x00);
        return true;
    }
    if (intf & IRQ_RX1IF) {
        readRxBuffer(REG_RXB1SIDH, out);
        bitModify(REG_CANINTF, IRQ_RX1IF, 0x00);
        return true;
    }
    return false;
}

bool CanDriver::send(const CanFrame& frame) {
    // Wait for the previous transmission to finish (a frame takes ~230 us
    // at 500 kbit/s, so 2 ms is a generous bound).
    uint32_t start = micros();
    while (readRegister(REG_TXB0CTRL) & TXREQ) {
        if (micros() - start > 2000) return false;
    }

    uint8_t buf[13];
    buf[0] = static_cast<uint8_t>(frame.id >> 3);
    buf[1] = static_cast<uint8_t>((frame.id & 0x07) << 5);
    buf[2] = 0x00;
    buf[3] = 0x00;
    buf[4] = frame.dlc & 0x0F;
    for (uint8_t i = 0; i < 8; ++i) buf[5 + i] = frame.data[i];
    writeRegisters(REG_TXB0SIDH, buf, 13);

    hal::SpiLock lock;
    SPI.beginTransaction(kSpiSettings);
    digitalWrite(cs_pin_, LOW);
    SPI.transfer(CMD_RTS_TXB0);
    digitalWrite(cs_pin_, HIGH);
    SPI.endTransaction();
    return true;
}
